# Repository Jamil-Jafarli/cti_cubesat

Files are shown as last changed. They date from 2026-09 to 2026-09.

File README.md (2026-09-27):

# Honeypot CubeSat CTI

A bench prototype of a **space cyber-threat-intelligence (CTI) platform built
on honeypot CubeSats**: a decoy satellite listens to its uplink, measures and
scores every frame it receives, fingerprints the transmitter, and sends its
records to a ground station that turns them into alerts, attacker profiles
and shareable indicators. The same board, switched to member mode, becomes
the accept/block gate a protected satellite would run.

The bench runs the whole chain over a real radio link with three low-cost
nodes: a Raspberry Pi Pico that plays ground stations and attackers, an ESP32
honeypot node, and a Raspberry Pi 4 ground station with a web portal.

| Uplink transmitter | Honeypot node | CTI ground station |
|---|---|---|
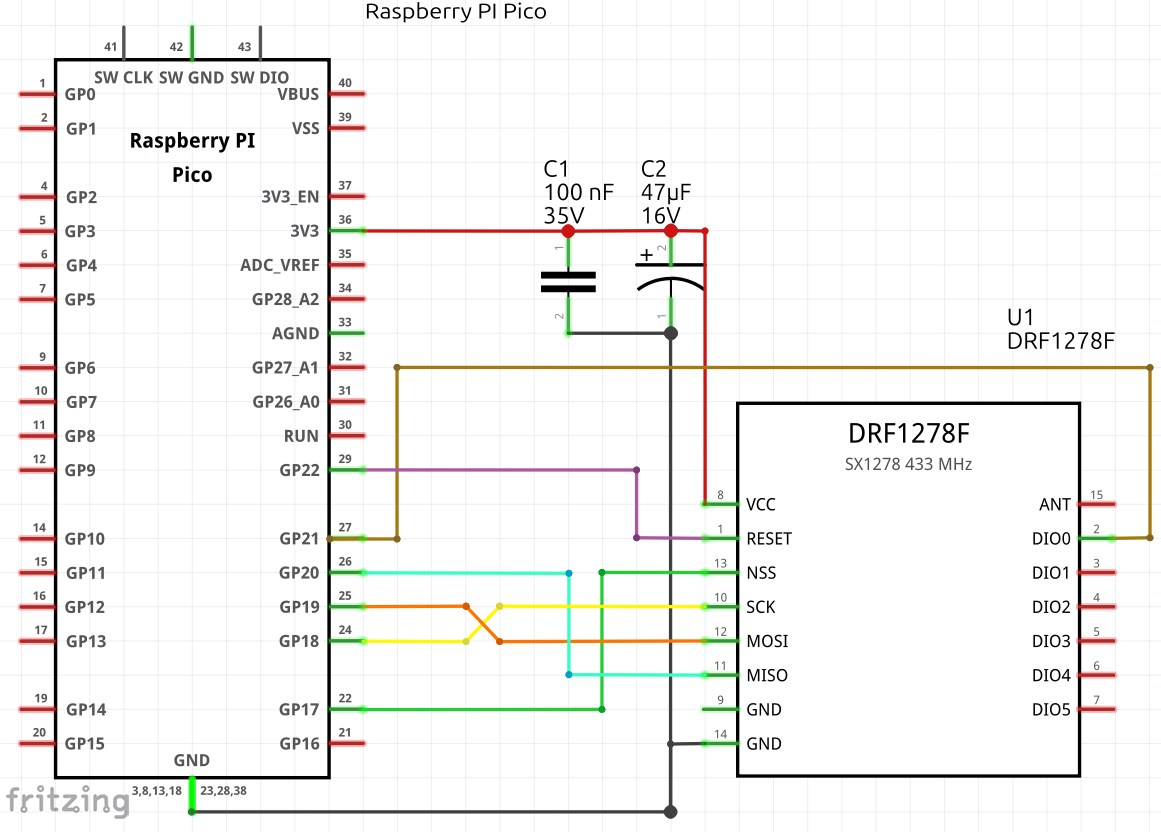
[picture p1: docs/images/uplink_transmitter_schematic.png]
Uplink transmitter schematic
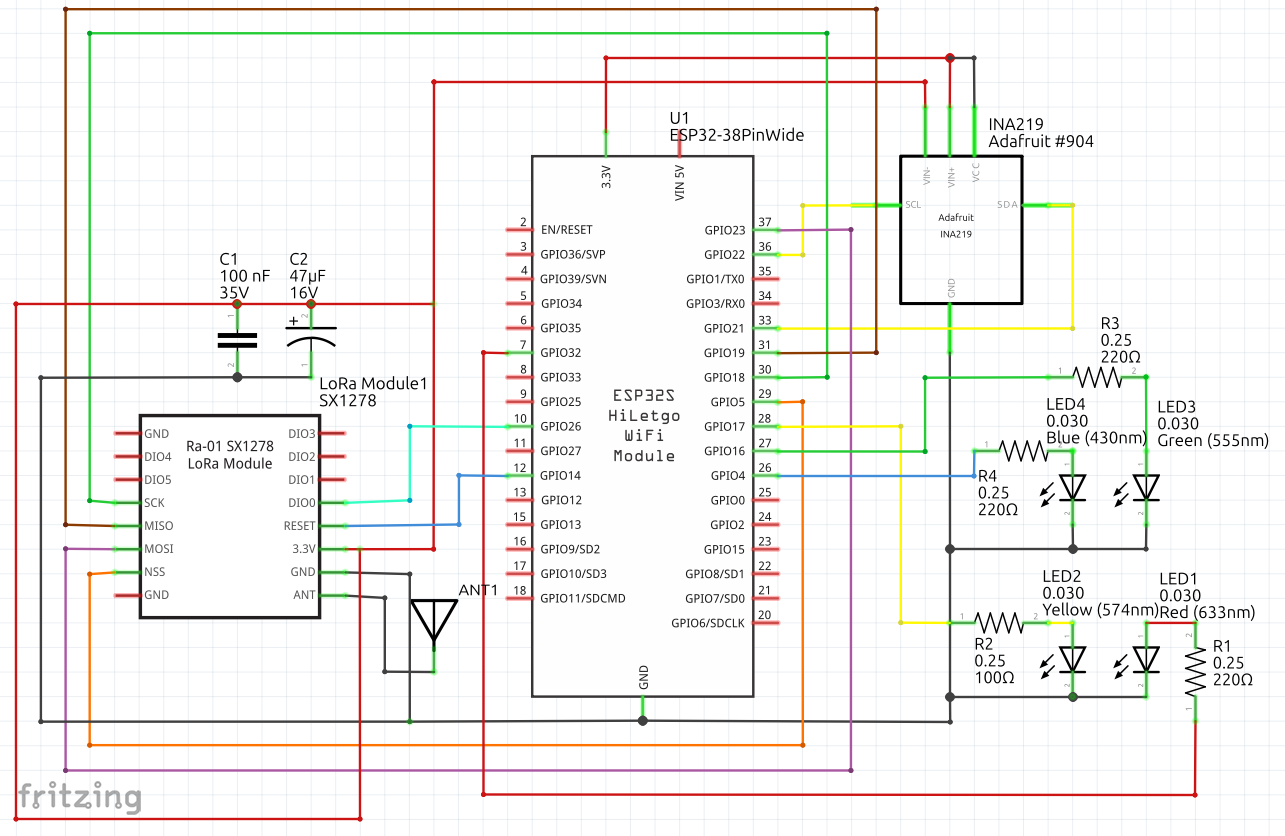
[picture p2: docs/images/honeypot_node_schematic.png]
Honeypot node schematic
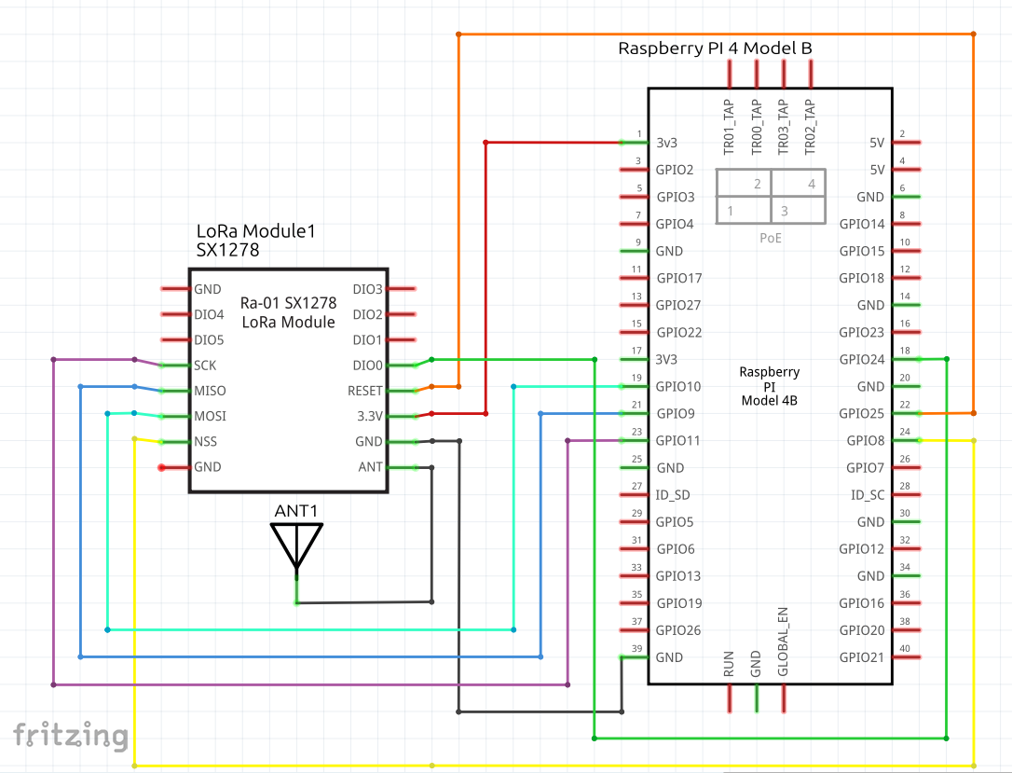
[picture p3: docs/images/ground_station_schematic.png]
Ground station schematic
|  |  |  |
| Raspberry Pi Pico + DRF1278F | ESP32 + Ra-01 + INA219 | Raspberry Pi 4 + Ra-01 |

## Contents

- [How it works](#how-it-works)
- [Results](#results)
- [Repository layout](#repository-layout)
- [Quick start without hardware](#quick-start-without-hardware)
- [Building the bench](#building-the-bench)
- [Running a session](#running-a-session)
- [Detection in brief](#detection-in-brief)
- [Reproducing the results](#reproducing-the-results)
- [Limitations](#limitations)
- [Documentation](#documentation)
- [Safety and regulations](#safety-and-regulations)
- [Background](#background)
- [License](#license)

## How it works

The concept has three parts:

- **Honeypot satellites** look like ordinary CubeSats, accept a small set of
  harmless commands, and record the RF metadata of every uplink frame,
  valid or not. They are the sensors of the network.
- The **ground platform** receives their records, analyses them, and builds
  the CTI database: alerts, attacker profiles, transmitter signatures.
- **Member satellites** run the same board as a gate: before a command is
  executed, the board checks it against the ground-built blocklist and its
  own allowlist, and answers accept or block.

The bench maps these onto three nodes:

```
  Uplink transmitter             Honeypot node                     CTI ground station
  Raspberry Pi Pico + DRF1278F   ESP32 + Ra-01 + INA219            Raspberry Pi 4 + Ra-01
 ┌─────────────────────────┐    ┌────────────────────────────┐    ┌────────────────────────────┐
 │ five ground stations    │    │ carrier offset (AFC), RSSI │    │ cti_receiver               │
 │ and five attack types   │    │ 7-indicator anomaly score  │    │ hny_server.py:             │
 │ AX.25 UI frames, 2-FSK  │───▶│ fuzzy transmitter match    │───▶│  SQLite, pass fit,         │
 │ 433.5 MHz, 2 dBm        │ RF │ fingerprint whitelist      │ RF │  9 detection rules,        │
 │ simulated pass Doppler  │    │ record stored in flash     │    │  profiles, STIX/MISP/CSV   │
 └─────────────────────────┘    │ member mode: accept/block  │    │ web portal on port 8700    │
          uplink                └────────────────────────────┘    └────────────────────────────┘
                                   downlink of stored records
```

All three radios are SX1278 transceivers driven by the same library
(RadioLib 7.7.1) and the same framing and detection code
(`libraries/HnyProto`), so the ground station also serves as a reference
receiver for the uplink.

A flight version, a 1U CubeSat plug-in board with the same ESP32 and a single
SX1278 receiver on one antenna, has been designed but not built. Everything
in this repository, and every number below, is from the bench.

## Results

From the bench campaign of 25 September 2026 (raw data in
[`data/`](data/2026-09-25-campaign), analysis in
[docs/reproducing.md](docs/reproducing.md)):

| Measurement | Result |
|---|---|
| Uplink capture, 15-minute scenario | 128 of 147 frames (87 %); 119 of 120 before the bench was physically disturbed |
| Carrier-offset accuracy, Doppler-free frames | −0.06 ± 0.20 kHz; 53 of 53 within ±0.4 kHz |
| Onboard processing per frame (ESP32, 240 MHz) | 290 µs mean, 347 µs max (x86_64 desktop: 195 µs) |
| Downlink of the stored records | 148 of 148, in each of two passes |
| Ground analysis | every attack record raised at least one alert, impersonations critical ones; no legitimate record flagged |
| Member mode | 11 of 11 frames from blocklisted sources blocked; 22 of 23 legitimate frames accepted |
| Honeypot throughput | 97 % capture at 0.9 s frame spacing, 9 % at 0.5 s |
| Radio power (Ra-01 supply) | 52 mW receiving, 228 mW transmitting at 2 dBm |
| Synthetic dataset (150 packets) | 32 of 32 injected attacks detected, no false positives |

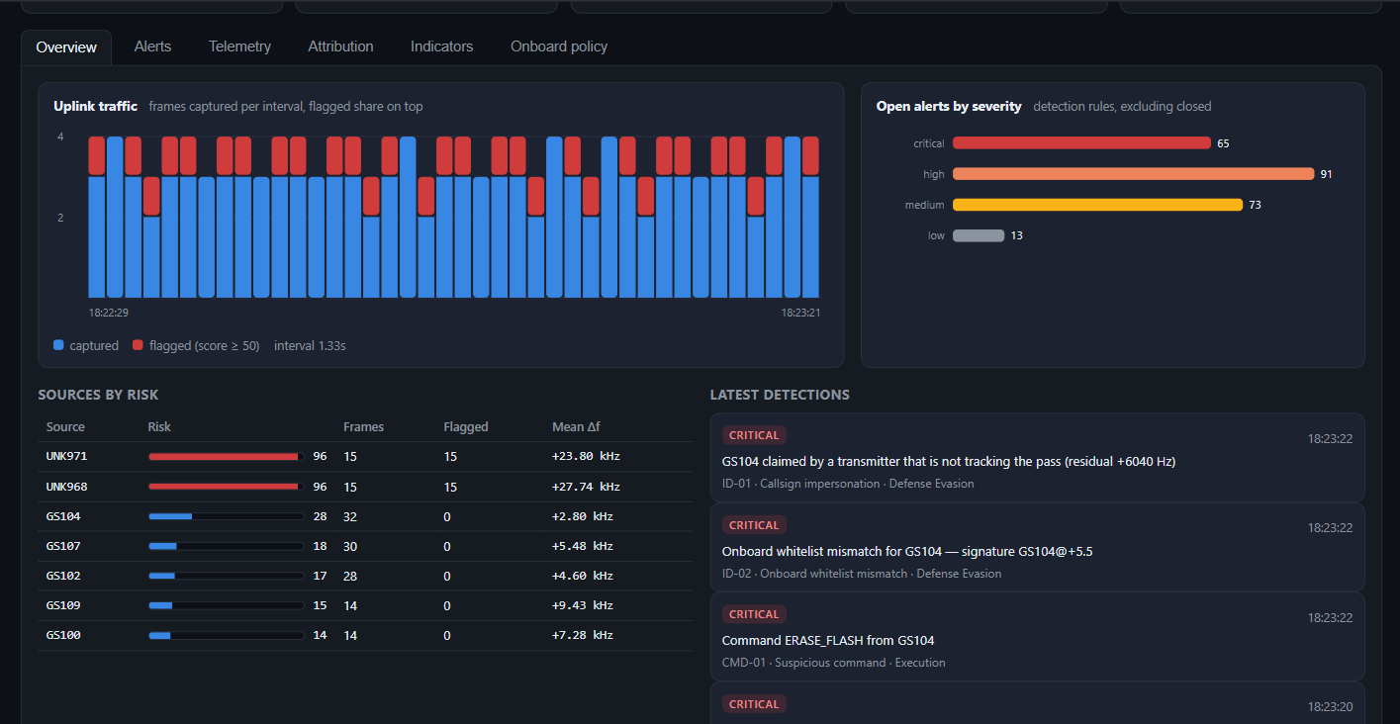
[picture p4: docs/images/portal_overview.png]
Portal overview


## Repository layout

```
firmware/
  honeypot_node/          ESP32: capture, score, fingerprint, store, downlink; member mode
  uplink_transmitter/     Pico: five ground stations and five attack types
  link_test/              Pico: numbered frames for link measurement and calibration
libraries/HnyProto/       shared header-only library: AX.25, registry, detection, record formats
ground_station/
  receiver/               cti_receiver: Raspberry Pi downlink receiver (C++, RadioLib + lgpio)
  server/                 hny_server.py, cti_engine.py, web portal, systemd unit
simulation/               synthetic-data pipeline: generator, detector, figures, dashboard
analysis/                 bench logger and the scripts behind the published figures
data/2026-09-25-campaign/ raw logs and ground database of the bench campaign
tools/uplink_monitor/     live view of the transmitted uplink (runs next to the Pico)
hardware/                 Fritzing sketches of the three nodes and a DRF1278F part
docs/                     hardware, firmware, ground station, protocol, detection, reproduction
```

## Quick start without hardware

The ground server and portal run on any computer with Python 3.10 or newer,
driven by the synthetic dataset:

```sh
git clone https://github.com/Jamil-Jafarli/cti_cubesat.git
cd cti_cubesat
pip install -r simulation/requirements.txt
cd ground_station/server
python3 hny_server.py --simulate --reset
# open http://127.0.0.1:8700
```

To re-run the detection pipeline on the synthetic data and produce its
figures, run `python3 export.py` in `simulation/`. For the Streamlit
dashboard, run `streamlit run dashboard.py` there.

## Building the bench

### Parts

| Node | Parts |
|---|---|
| Uplink transmitter | Raspberry Pi Pico, Dorji DRF1278F (SX1278, 433 MHz) |
| Honeypot node | ESP32-WROOM-32D DevKit, Ai-Thinker Ra-01 (SX1278, 433 MHz), INA219 breakout (0.1 Ω shunt), red / amber / green / blue LEDs with 300 / 200 / 300 / 200 Ω resistors |
| CTI ground station | Raspberry Pi 4 Model B, Ai-Thinker Ra-01 |
| Each radio | 100 nF ceramic + 10–47 µF electrolytic across 3.3 V and GND at the module; 17.3 cm wire antenna |

The radio modules are 3.3 V only and have 1.27 mm pads; solder thin wires to
them. The full bill of materials and notes on power, decoupling and antennas
are in [docs/hardware.md](docs/hardware.md).

### Wiring

**Uplink transmitter** (DRF1278F → Pico)

| DRF1278F | SCK | MOSI | MISO | NSS | RESET | DIO0 | VCC | GND |
|---|---|---|---|---|---|---|---|---|
| Pico | GP18 | GP19 | GP20 | GP17 | GP22 | GP21 | 3V3(OUT) | GND |

Uplink transmitter schematic

**Honeypot node** (Ra-01, INA219, LEDs → ESP32)

| Ra-01 | SCK | MISO | MOSI | NSS | RESET | DIO0 | 3.3V | GND |
|---|---|---|---|---|---|---|---|---|
| ESP32 | IO18 | IO19 | IO23 | IO5 | IO14 | IO26 | via INA219 (below) | GND |

| INA219 | VIN+ | VIN− | VCC | GND | SDA | SCL |
|---|---|---|---|---|---|---|
| connects to | ESP32 3V3 | Ra-01 3.3V | ESP32 3V3 | GND | IO21 | IO22 |

| LED (anode via resistor, cathode to GND) | red | amber | green | blue |
|---|---|---|---|---|
| ESP32 | IO32 | IO17 | IO16 | IO4 |

Honeypot node schematic

**CTI ground station** (Ra-01 → Raspberry Pi 4; header pin in brackets)

| Ra-01 | SCK | MISO | MOSI | NSS | RESET | DIO0 | 3.3V | GND |
|---|---|---|---|---|---|---|---|---|
| Pi 4 | GPIO11 (23) | GPIO9 (21) | GPIO10 (19) | GPIO8 / CE0 (24) | GPIO25 (22) | GPIO24 (18) | 3V3 (17) | GND (20) |

Ground station schematic

The ground-station schematic takes 3V3 and GND from header pins 1 and 39;
any 3V3 and GND pin works. The Fritzing sources of all three schematics are
in [`hardware/`](hardware).

### Firmware

Tested with the esp32 core 2.0.17, the arduino-pico (rp2040) core 6.1.0 and
RadioLib 7.7.1:

```sh
arduino-cli config add board_manager.additional_urls \
  https://github.com/earlephilhower/arduino-pico/releases/download/global/package_rp2040_index.json
arduino-cli core update-index
arduino-cli core install esp32:esp32@2.0.17 rp2040:rp2040@6.1.0
arduino-cli lib install RadioLib@7.7.1

arduino-cli compile -b esp32:esp32:esp32 --library libraries/HnyProto firmware/honeypot_node
arduino-cli upload  -b esp32:esp32:esp32 -p /dev/ttyUSB0 firmware/honeypot_node

arduino-cli compile -b rp2040:rp2040:rpipico --library libraries/HnyProto firmware/uplink_transmitter
arduino-cli upload  -b rp2040:rp2040:rpipico -p /dev/ttyACM0 firmware/uplink_transmitter
```

With the Arduino IDE, copy `libraries/HnyProto` into your sketchbook's
`libraries` folder and install RadioLib 7.7.1 from the Library Manager.
See [docs/firmware.md](docs/firmware.md) for configuration, serial output and
calibration.

### Ground station

On the Raspberry Pi (Raspberry Pi OS):

```sh
sudo apt install git cmake g++ liblgpio-dev python3
sudo raspi-config nonint do_spi 0
git clone https://github.com/Jamil-Jafarli/cti_cubesat.git ~/cti_cubesat
~/cti_cubesat/ground_station/receiver/build.sh
cd ~/cti_cubesat/ground_station/server
python3 hny_server.py --radio --host 0.0.0.0
# portal: http://<pi-address>:8700
```

To start it at boot, adjust and install `ground_station/server/cti-server.service`
(see [docs/ground-station.md](docs/ground-station.md)).

### Calibration

The two radios' crystals differ by a few kHz, and the difference changes when
a module is replaced or resoldered. Measure it once on your bench with
`firmware/link_test` and `analysis/linktest_analysis.py`, and set `CALIB_HZ`
in `firmware/honeypot_node/honeypot_node.ino`
([procedure](docs/firmware.md#calibration)). A calibrated node reads
Doppler-free frames to within ±0.4 kHz.

## Running a session

1. Power the three nodes 1–2 m apart, each with its antenna.
2. Open the honeypot's serial monitor (115200 baud). At boot it reports the
   INA219, the noise floor and its RSSI trigger level.
3. Let the uplink transmitter run. Every frame the honeypot receives prints an
   `[rx]` line with the measured offset, score, class and whitelist state, and
   the LEDs show the last verdict. `tools/uplink_monitor` shows the
   transmitted side live.
4. Stop the transmitter and send `D` to the honeypot (or press BOOT). Its
   stored records are downlinked, analysed on the ground and shown in the
   portal.

Honeypot serial commands:

| Key | Action |
|---|---|
| `D` | downlink every stored record |
| `S` | status JSON: store, receiver counters, processing time, heap, stack |
| `E` | erase the record store |
| `R` | reset the timing counters |
| `M` | toggle honeypot / member mode |
| `F` / `A` / `X` | show the whitelist / enrol the last transmitter / clear the whitelist |
| `P` | radio power profile (receive, standby, sleep, 2 dBm carrier) via the INA219 |
| `Q` | RSSI scan of 433.40–433.60 MHz (all transmitters off) |

## Detection in brief

Every frame gets an anomaly score of 0–100 from seven weighted indicators;
50 or more flags it:

| Indicator | Fires when | Weight |
|---|---|---:|
| Frequency deviation | carrier more than 20 kHz off the centre | 25 |
| Doppler mismatch | Doppler residual larger than 700 Hz | 25 |
| Unexpected modulation | modulation differs from the expected profile | 15 |
| Suspicious command | e.g. `REBOOT`, `ERASE_FLASH`, an unknown opcode | 15 |
| Malformed packet | AX.25 FCS does not verify | 10 |
| Unknown source | callsign not in the registry | 5 |
| Probing | less than 2 s since the previous frame | 5 |

Independently, a fuzzy match against the ground-station registry classifies
the transmitter as known, suspicious or attacker:

```
S = 0.45 · (1 − |Δfreq| / 25 kHz) + 0.25 · (1 − |Δdrift| / 1 ppm) + 0.30 · [modulation matches]
```

A callsign is only text, so the honeypot binds each whitelisted callsign to
the carrier offset its real transmitter uses (the **transmitter signature**,
e.g. `GS104@+0.0`). A frame that carries an enrolled callsign from a
different radio is reported as a whitelist mismatch, and in member mode it
loses the allowlist override.

On the ground, the server fits the pass to all records, recomputes every
score, and runs nine rules (off-frequency carrier, Doppler residual, callsign
impersonation, whitelist mismatch, suspicious command, unregistered source,
probing burst, malformed frame, sustained campaign). It groups records into
source profiles with a risk score and offers callsigns, signatures and
commands as indicators with confidence and TLP marking, exportable as
STIX 2.1, MISP or CSV. Details: [docs/detection.md](docs/detection.md).

## Reproducing the results

```sh
cd analysis
python3 scenario_analysis.py ../data/2026-09-25-campaign/scenario_run.json ../data/2026-09-25-campaign/ground.db
python3 member_analysis.py   ../data/2026-09-25-campaign/member_run.json
python3 linktest_analysis.py ../data/2026-09-25-campaign/linktest_900ms.json
```

These reproduce the numbers in [Results](#results) from the raw campaign
data. [docs/reproducing.md](docs/reproducing.md) shows the expected output and
how to run the same measurements on your own bench.

## Limitations

- **Synthetic and scripted evaluation.** The detection rates come from a
  synthetic dataset whose anomalies follow the same features the detector
  scores, and the bench scenarios were written by us. Neither reflects an
  adaptive, real attacker.
- **Prototype figures.** All measurements are from a classic ESP32 and one
  SX1278 per node. The power of the whole node was not measured (only the
  radio's), and capture depended on the physical state of the bench.
- **Throughput.** The honeypot scores, fingerprints and writes each frame to
  flash before it listens again, so it loses most frames sent faster than
  about one per second. A transmitter can use this to blind it. Buffering
  records in RAM and writing them off the receive path is the obvious fix and
  is not implemented.
- **Modulation.** An SX127x packet receiver decodes only its own modulation,
  so the unexpected-modulation indicator never fires on the bench. It needs a
  receiver with IQ output or an SDR.
- **Fingerprint resolution.** The bench measures the carrier offset to about
  0.4 kHz and cannot measure oscillator drift, while the registry assumes
  sub-kHz signatures. The 1:N fuzzy match only works on a small,
  mission-specific registry; a decision about a claimed identity should rest
  on the 1:1 whitelist check.
- **Onboard Doppler estimate.** Without an orbit model the honeypot estimates
  the pass Doppler from the cooperating stations. The estimate lags the
  fastest part of the pass, needs about 20 s after a restart, and assumes the
  cooperating stations are the majority of the traffic.
- **Whitelist enrolment** is trust on first use.
- **Not implemented:** distribution of the CTI blocklist to member
  satellites, transmitter geolocation from the Doppler curve, a TAXII server,
  authentication of the portal and API.

## Documentation

| Document | Content |
|---|---|
| [docs/hardware.md](docs/hardware.md) | bill of materials, wiring, schematics, power, antennas, Fritzing files |
| [docs/firmware.md](docs/firmware.md) | toolchain, build and upload, configuration, serial commands and output, calibration |
| [docs/ground-station.md](docs/ground-station.md) | Raspberry Pi setup, server options, systemd, portal, HTTP API, troubleshooting |
| [docs/protocol.md](docs/protocol.md) | radio channel, AX.25 frames, record and downlink formats |
| [docs/detection.md](docs/detection.md) | indicators, fuzzy match, signatures and whitelist, member mode, ground rules, profiles, indicators |
| [docs/reproducing.md](docs/reproducing.md) | reproducing every published figure from the raw data, and on your own bench |

## Safety and regulations

The bench transmits at 2 dBm on 433.5 MHz, inside the 433.05–434.79 MHz ISM
band, over a distance of 1–2 m. Check the rules for short-range devices in
your country before transmitting, and always connect an antenna before a
radio transmits. The flight concept uses the amateur-satellite band, which
requires a licence. This project is for research and education: do not
transmit to satellites you do not operate.

## Background

The bench was built for the paper *Space Cyber Threat Intelligence Platform
Using Honeypot CubeSats for Attacker Identification*, prepared for the
International Astronautical Congress (IAC 2026).

The project builds on RadioLib, lgpio, Streamlit, pandas and matplotlib, and
on community Fritzing parts for the Ra-01, ESP32 DevKit, INA219 and
Raspberry Pi Pico.

## License

MIT, see [LICENSE](LICENSE). Third-party components (RadioLib, lgpio, the
Python packages and the community Fritzing parts) keep their own licences.

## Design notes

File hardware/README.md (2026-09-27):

# Hardware files

| File | Content |
|---|---|
| `fritzing/uplink_transmitter.fzz` | Raspberry Pi Pico + DRF1278F |
| `fritzing/honeypot_node.fzz` | ESP32 DevKit + Ra-01 + INA219 + four LEDs |
| `fritzing/ground_station.fzz` | Raspberry Pi 4 + SX1278 radio (drawn with the DRF1278F symbol; the bench uses a Ra-01 with the same connections) |
| `fritzing/parts/DRF1278F_Dorji_SX1278.fzpz` | Fritzing part for the Dorji DRF1278F (17 × 17 mm, 15 castellated pads at 1.27 mm), made from the DRF1278F datasheet Rev 1.1 |

Open the part file in Fritzing first (File → Open), so that the sketches that
use it find it. The other parts are embedded in the sketches.

Wiring tables, the bill of materials and notes on power and antennas are in
[docs/hardware.md](../docs/hardware.md).

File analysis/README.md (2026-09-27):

# Analysis

| Script | Purpose |
|---|---|
| `benchlog.py` | logs the transmitter Pico and the honeypot side by side with host timestamps (needs pyserial) |
| `benchparse.py` | shared parsing and frame matching |
| `linktest_analysis.py` | link test: capture and carrier-offset error per offset; calibration |
| `scenario_analysis.py` | scenario run: capture, onboard and ground verdicts, carrier-offset error, alerts per scenario |
| `member_analysis.py` | member-mode run: verdicts per scenario |

```sh
python3 scenario_analysis.py ../data/2026-09-25-campaign/scenario_run.json ../data/2026-09-25-campaign/ground.db
```

The full procedure and the expected output are in
[docs/reproducing.md](../docs/reproducing.md).

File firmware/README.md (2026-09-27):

# Firmware

| Sketch | Board | Role |
|---|---|---|
| [`honeypot_node`](honeypot_node/honeypot_node.ino) | ESP32 Dev Module | the honeypot's detection board: capture, score, fingerprint, store, downlink; member mode |
| [`uplink_transmitter`](uplink_transmitter/uplink_transmitter.ino) | Raspberry Pi Pico | uplink scenario: five ground stations and five attack types |
| [`link_test`](link_test/link_test.ino) | Raspberry Pi Pico | link measurement and calibration |

All sketches need RadioLib 7.7.1 and the shared library in
[`../libraries/HnyProto`](../libraries/HnyProto):

```sh
arduino-cli compile -b esp32:esp32:esp32     --library libraries/HnyProto firmware/honeypot_node
arduino-cli compile -b rp2040:rp2040:rpipico --library libraries/HnyProto firmware/uplink_transmitter
arduino-cli compile -b rp2040:rp2040:rpipico --library libraries/HnyProto firmware/link_test
```

Each sketch starts with a header that lists its wiring, build settings and
serial commands. Toolchain, configuration, serial output and calibration are
described in [docs/firmware.md](../docs/firmware.md).

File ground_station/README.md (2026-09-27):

# Ground station

Runs on a Raspberry Pi 4 with a Ra-01 on SPI0.

| Folder | Content |
|---|---|
| [`receiver`](receiver) | `cti_receiver` (C++, RadioLib + lgpio): receives the honeypot's downlink and prints one `CTI,<csv>` line per record |
| [`server`](server) | `hny_server.py`: stores the records (SQLite), runs the ground analysis and serves the portal on port 8700; `cti_engine.py`: detection rules, profiles, indicators and STIX/MISP/CSV export; `web/`: the portal; `cti-server.service`: systemd unit |

```sh
sudo apt install cmake g++ liblgpio-dev python3
sudo raspi-config nonint do_spi 0
receiver/build.sh
cd server && python3 hny_server.py --radio --host 0.0.0.0
```

Without hardware: `python3 hny_server.py --simulate --reset` (needs
`simulation/requirements.txt`). Setup, options, the portal, the HTTP API and
troubleshooting are described in [docs/ground-station.md](../docs/ground-station.md).

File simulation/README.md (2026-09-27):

# Simulation

The synthetic-data version of the detection pipeline: it generates labelled
uplink telemetry for three simulated honeypot satellites, scores it with the
same indicators and fuzzy match as the firmware, and produces CTI records,
figures and a dashboard.

| File | Content |
|---|---|
| `profiles.py` | node frequencies, ground-station registry, indicator weights and thresholds |
| `generator.py` | synthetic telemetry: legitimate passes with Doppler and drift, and injected attacks |
| `detector.py` | anomaly score, fuzzy transmitter match, CTI records, evaluation |
| `database.py` | SQLite storage of CTI records |
| `export.py` | the whole pipeline: data, records, figures and the evaluation printout |
| `profile_resources.py` | processing time, memory and throughput of the pipeline |
| `dashboard.py` | Streamlit dashboard |

```sh
pip install -r requirements.txt
python3 export.py                  # writes data/ and out/, prints the evaluation
python3 profile_resources.py       # timing on this machine
streamlit run dashboard.py         # interactive dashboard
```

The ground server's `--simulate` mode imports `generator.py` and `detector.py`
from here to fill the portal without hardware.

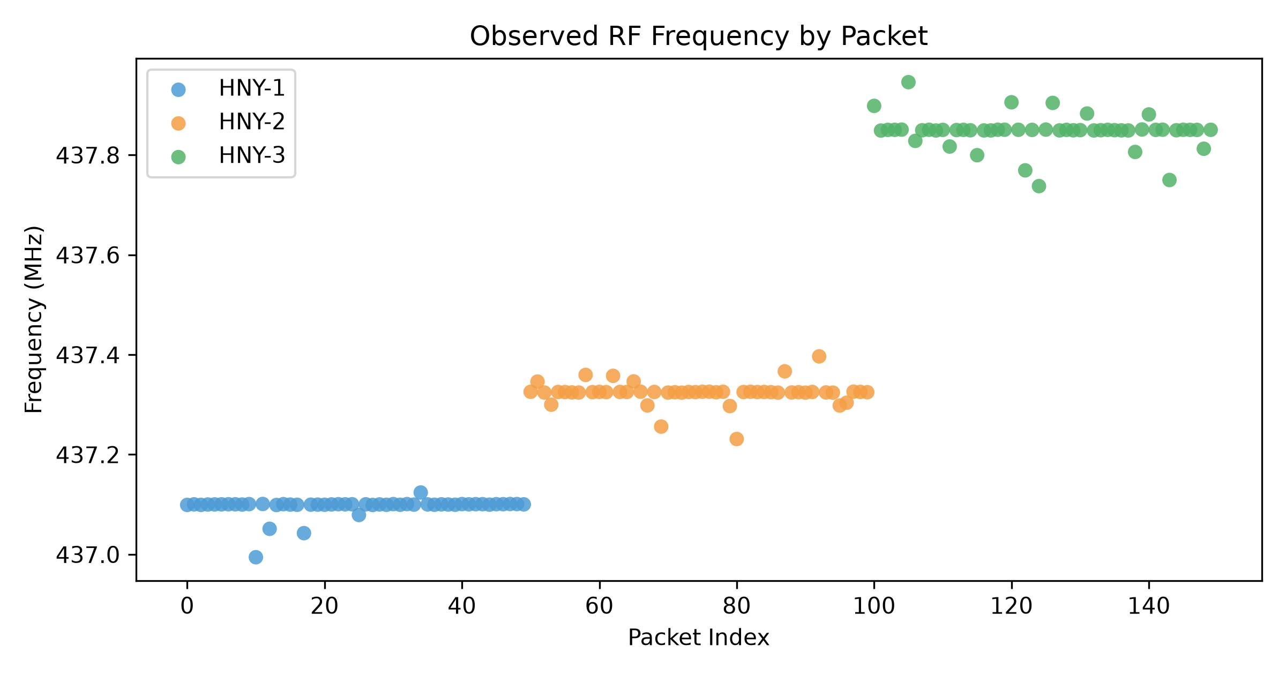
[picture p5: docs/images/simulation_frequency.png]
Carrier frequency per packet


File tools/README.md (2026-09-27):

# Tools

## Uplink monitor

`uplink_monitor/uplink_monitor.py` shows the frames the uplink transmitter
sends, live, in a browser. Run it on the computer the Pico is connected to:

```sh
python3 tools/uplink_monitor/uplink_monitor.py --serial /dev/ttyACM0
python3 tools/uplink_monitor/uplink_monitor.py --demo      # no hardware
# open http://127.0.0.1:8701
```

It reads the `[up] ...` lines of `firmware/uplink_transmitter`, keeps the last
400 frames in memory and stores nothing on disk. Only the standard library is
needed, plus pyserial for `--serial`. The serial port can be read by only one
program at a time, so stop `analysis/benchlog.py` while the monitor runs.

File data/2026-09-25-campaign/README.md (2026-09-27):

# Bench campaign, 25 September 2026

Raw data of the measurement campaign reported in the documentation
([docs/reproducing.md](../../docs/reproducing.md)). Radio supply of the
honeypot: ESP32 3V3 → INA219 → Ra-01. Honeypot store and ground database
were empty at the start.

| File | Content |
|---|---|
| `scenario_run.json` | 15-minute run of `firmware/uplink_transmitter`: transmitter log (`pico`) and honeypot log (`esp`), host timestamps |
| `ground.db` | ground-station database after the downlink (148 of 148 records): tables `packets`, `alerts`, `indicator_state` |
| `honeypot_status.json` | the honeypot's status report (`S`) after the uplink: processing time, heap, stack, receiver counters |
| `power.json` | three runs of the honeypot's radio power profile (`P`) |
| `linktest_900ms.json` | `firmware/link_test` at 0.9 s frame spacing, transmitter and honeypot logs |
| `linktest_500ms.json` | the same at 0.5 s frame spacing |
| `member_run.json` | 6-minute run with the honeypot in member mode, after the bench had been disturbed |

The honeypot's serial log becomes unreliable after about 800 s of the scenario
run (USB passthrough), so capture is computed from the ground database, which
holds the honeypot's complete store.

```sh
cd analysis
python3 scenario_analysis.py ../data/2026-09-25-campaign/scenario_run.json ../data/2026-09-25-campaign/ground.db
```

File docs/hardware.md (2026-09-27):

# Hardware

The bench has three nodes. All three radios are SX1278 transceivers on the
433 MHz ISM band, driven by the same library (RadioLib 7.7.1) and the same
framing code (`libraries/HnyProto`).

| Node | Role | Board | Radio |
|---|---|---|---|
| Uplink transmitter | plays five ground stations and an attacker | Raspberry Pi Pico | Dorji DRF1278F |
| Honeypot node | the CubeSat's detection board | ESP32-WROOM-32D development board | Ai-Thinker Ra-01 |
| CTI ground station | receives the downlink, runs the server and portal | Raspberry Pi 4 Model B | Ai-Thinker Ra-01 |

## Bill of materials

| Qty | Part | Notes |
|---|---|---|
| 1 | Raspberry Pi Pico | uplink transmitter (the same board runs the link test) |
| 1 | Dorji DRF1278F module (SX1278, 433 MHz) | castellated, 1.27 mm pitch |
| 1 | ESP32-WROOM-32D development board | 30- or 38-pin DevKit, "ESP32 Dev Module" in the Arduino IDE |
| 2 | Ai-Thinker Ra-01 module (SX1278, 433 MHz) | honeypot node and ground station, 1.27 mm pitch |
| 1 | INA219 current-monitor breakout, 0.1 Ω shunt | radio supply monitor on the honeypot node |
| 1 | Raspberry Pi 4 Model B, Raspberry Pi OS | ground station |
| 4 | 3 mm or 5 mm LEDs: red, amber, green, blue | verdict indicators |
| 4 | resistors: 220 Ω (red, green, blue), 100 Ω (amber) | LED series resistors |
| 3 | 100 nF ceramic capacitor | one per radio module |
| 3 | 10–47 µF electrolytic capacitor, ≥ 6.3 V | one per radio module |
| 3 | 17.3 cm straight wire (or a 433 MHz spring antenna) | quarter-wave antenna for each radio |
| – | perfboard, thin wire, headers, USB cables | |

The SX1278 modules are 3.3 V parts: never connect them to 5 V. Both module
types have 1.27 mm pads and do not fit a breadboard; solder thin wires to them
or use a breakout adapter.

## Wiring

Pins are given by name. On the Raspberry Pi 4 the physical header position is
added, because the header itself is not labelled.

### Uplink transmitter: DRF1278F → Raspberry Pi Pico

| DRF1278F | Pico |
|---|---|
| SCK | GP18 |
| MOSI | GP19 |
| MISO | GP20 |
| NSS | GP17 |
| RESET | GP22 |
| DIO0 | GP21 |
| VCC | 3V3(OUT) |
| GND (both) | GND |
| ANT | 17.3 cm wire |

MISO must be an SPI0 RX-capable pin (GP0, GP4, GP16 or GP20); change `PIN_MISO`
in the sketch if you use another one. DIO1–DIO5 stay unconnected.

Uplink transmitter schematic

### Honeypot node: Ra-01, INA219 and LEDs → ESP32

| From | To (ESP32) |
|---|---|
| Ra-01 SCK | IO18 |
| Ra-01 MISO | IO19 |
| Ra-01 MOSI | IO23 |
| Ra-01 NSS | IO5 |
| Ra-01 RESET | IO14 |
| Ra-01 DIO0 | IO26 |
| Ra-01 3.3V | INA219 VIN− |
| INA219 VIN+ | 3V3 (a separate wire) |
| INA219 VCC | 3V3 |
| INA219 GND | GND |
| INA219 SDA | IO21 |
| INA219 SCL | IO22 |
| Ra-01 GND (all three) | GND |
| red LED anode, through 220 Ω | IO32 |
| amber LED anode, through 100 Ω | IO17 |
| green LED anode, through 220 Ω | IO16 |
| blue LED anode, through 220 Ω | IO4 |
| LED cathodes | GND |

The radio's supply runs ESP32 3V3 → INA219 VIN+ → shunt → VIN− → Ra-01 3.3V,
so the INA219 measures the radio's current and nothing else. The node works
without the INA219 if VIN+ and VIN− are bridged; only the `P` power profile is
then unavailable.

Keep IO0 (BOOT button), IO2, IO12, IO15 and IO6–IO11 free. IO16 and IO17 are
free on WROOM modules only; on a WROVER board move the green and amber LEDs
to other pins. IO25 is an optional COM_TX_ACTIVE input (active low, internal
pull-up) that parks the receiver while the satellite's own radio transmits;
leave it unconnected on the bench.

LED meanings:

| LED | Honeypot mode | Member mode |
|---|---|---|
| red | flagged or classified as attacker | blocked |
| amber | suspicious | allowlist override or spoof suspect |
| green | known ground station | accepted |
| blue | downlink in progress | downlink in progress |

The red, amber and green LEDs hold the last verdict until the next frame.

Honeypot node schematic

### CTI ground station: Ra-01 → Raspberry Pi 4

| Ra-01 | Raspberry Pi 4 | Header pin |
|---|---|---|
| 3.3V | 3V3 | 17 |
| GND | GND | 20 |
| SCK | GPIO11 (SPI0 SCLK) | 23 |
| MISO | GPIO9 (SPI0 MISO) | 21 |
| MOSI | GPIO10 (SPI0 MOSI) | 19 |
| NSS | GPIO8 (SPI0 CE0) | 24 |
| RESET | GPIO25 | 22 |
| DIO0 | GPIO24 | 18 |
| ANT | 17.3 cm wire | – |

Header pin 1 is the corner farthest from the USB and Ethernet ports (square
solder pad); odd pins are on the inner row. Pins 2 and 4 carry 5 V; do not
connect the radio there. The kernel's SPI driver drives NSS (CE0), so SPI must
be enabled (`sudo raspi-config nonint do_spi 0`).

The schematic below takes 3V3 and GND from header pins 1 and 39; any 3V3 and
GND pin works.

Ground station schematic

## Power and decoupling

Put a 100 nF ceramic and a 10–47 µF electrolytic capacitor across each radio
module's 3.3 V and GND, as close to the module as possible (positive lead of
the electrolytic to 3.3 V). On the bench, supply dips at the radio were enough
to reset the SX1278 without resetting the microcontroller; the firmware
detects this and reconfigures the radio, but good decoupling prevents it.

Power the radios from the boards' own 3.3 V regulators. On the honeypot node
a separate switching converter in the radio supply added noise next to the
receiver and a voltage drop on mode changes, and was removed.

## Antennas and placement

Each radio needs an antenna: a 17.3 cm straight wire soldered to ANT (a
quarter wave at 433 MHz) or a 433 MHz spring antenna. Never transmit without
an antenna. Keep the Ra-01 at least 3 cm from the ESP32 board's own PCB
antenna. The bench runs at 2 dBm over 1–2 m; the received level is typically
−40 to −60 dBm.

## Fritzing files

`hardware/fritzing/` holds the Fritzing sketches of the three nodes and a
Fritzing part for the Dorji DRF1278F, which is not in the standard library.
Import `parts/DRF1278F_Dorji_SX1278.fzpz` first (File → Open), then open the
sketches. The Ra-01, ESP32 DevKit, INA219 and Raspberry Pi Pico parts are
embedded in the sketches; they come from community part libraries.

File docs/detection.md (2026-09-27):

# Detection

Detection runs in two tiers. The honeypot node scores every frame as it
arrives, fingerprints the transmitter and stores a record. The ground station
receives the stored records, analyses the whole pass again with information
the satellite does not have, raises alerts and builds the threat-intelligence
picture. The ground figures are the authoritative ones; the onboard score is
kept alongside for comparison.

The same constants are defined in `libraries/HnyProto/HnyProto.h` (firmware),
`simulation/profiles.py` (synthetic pipeline) and
`ground_station/server/cti_engine.py` (ground analysis).

## Anomaly score

Every frame gets a score of 0–100, the sum of seven weighted binary
indicators:

| Indicator | Fires when | Weight |
|---|---|---:|
| Frequency deviation | carrier more than 20 kHz from the node's centre frequency | 25 |
| Doppler mismatch | Doppler residual larger than 700 Hz | 25 |
| Unexpected modulation | modulation differs from the expected profile (GFSK in the model) | 15 |
| Suspicious command | `REBOOT`, `OVERRIDE`, `ERASE_FLASH`, `SET_MODE=DEBUG`, `DISABLE_COMMS` or an unknown opcode | 15 |
| Malformed packet | AX.25 FCS does not verify | 10 |
| Unknown source | callsign not in the ground-station registry | 5 |
| Probing | less than 2 s since the previous frame | 5 |

A frame with a score of 50 or more is **flagged**, and a CTI record is
created for it. Its confidence is `min(89.15, 42 + 0.53 × score)`; the cap is
a calibration constant, not a measured value.

On the bench the modulation indicator never fires: an SX127x packet receiver
decodes only its own modulation and sees any other one as signal strength
alone. Recognising foreign modulations needs a receiver with IQ output or an
SDR at the ground station.

The Doppler residual is the carrier offset left after the pass Doppler and
the transmitter's known offset are removed. A cooperating ground station
pre-compensates the pass Doppler, so its residual is near zero; a transmitter
without an orbit model (a typical ground attacker) stays on a fixed frequency,
and its residual follows the whole pass profile.

## Fuzzy transmitter match

Independently of the score, every frame is compared with each of the 16
ground stations in the registry. A station's signature is the residual
carrier offset of its transmitter (sub-kHz for TCXO-class references) and its
short-term oscillator drift (ppm). The similarity with one entry is

```
S = 0.45 · (1 − |Δfreq| / 25 kHz)
  + 0.25 · (1 − |Δdrift| / 1 ppm)
  + 0.30 · [modulation matches]
```

with each term clipped at zero. The best match over the registry classifies
the transmitter as **known** (S ≥ 0.85), **suspicious** (0.60 ≤ S < 0.85) or
**attacker** (S < 0.60).

The bench measures the carrier offset to about 0.4 kHz and cannot measure
oscillator drift at all (the firmware passes zero), so on the bench the
ranking rests on the frequency term. The portal shows the three weighted
terms, the runner-up and the margin for every frame, so a classification that
rests on an unmeasured term is visible as such.

The fuzzy match is a 1:N identification and only works on a small,
mission-specific registry. With thousands of stations in one database almost
any ordinary transmitter would sit within 1 kHz of some entry and be
classified as `known` under another station's name. Decisions about a claimed
identity should therefore rest on a 1:1 check of the claimed callsign's own
signature, which is what the whitelist below does.

## Transmitter signature and fingerprint whitelist

The per-record SHA-256 identifier changes with every frame, so nothing can be
whitelisted on it. What does persist from frame to frame is the physical
layer the transmitter cannot easily change: the carrier offset its oscillator
lands on. Quantised to 0.5 kHz and paired with the claimed callsign, it forms
the **transmitter signature**:

```
GS104@+0.0     the operator's own station, as enrolled
GS104@+24.5    somebody else transmitting GS104's callsign
```

The honeypot keeps a small whitelist of signatures (up to 8 entries, stored
in flash). Each entry holds a callsign, an enrolled offset and a tolerance
(1.5 kHz). A frame is checked against it on its Doppler-free residual and
gets one of three states:

| State | Meaning |
|---|---|
| none | no entry for this callsign: the whitelist has no opinion |
| match | the callsign is enrolled and the offset is within tolerance |
| mismatch | the callsign is enrolled, but the frame came from a different transmitter |

Entries are enrolled deliberately: send `A` to the honeypot right after a
known-good frame. A flight build would fill the table before launch and
update it only through an authenticated uplink. Enrolment is trust on first
use: an impersonator transmitting during enrolment would be enrolled.

### Onboard Doppler estimate

The whitelist must be checked on the residual, and the bench board has no
orbit model. Every cooperating station pre-compensates the same pass profile,
so subtracting each station's known offset from its measured offset leaves
the common Doppler motion. The median of the last eight such samples
estimates it; a fixed-frequency attacker is an outlier the median ignores.
The estimate needs three samples from known callsigns before it is used
(about 20 s on the bench scenario); until then the residual is the raw offset.

Limits of this estimate: the median lags the fastest part of the pass, so a
legitimate frame can briefly exceed the 700 Hz threshold; and it assumes the
cooperating stations are the majority of the traffic. A flight board would
take the Doppler from its orbit propagator instead.

## Member mode

On a member satellite the board is a gate, not a sensor. For every uplink
frame it gives the on-board computer a verdict and stores nothing. Two lists
decide:

- the **allowlist**: the satellite's own ground stations; it always wins, so
  an attacker cannot get a legitimate station blocked by imitating it;
- the **blocklist**: transmitter signatures from the ground platform
  (callsign plus carrier offset within a tolerance). Only entries with a
  confidence of 80 or more are acted on.

| Situation | Verdict |
|---|---|
| blocklist match, callsign not allowlisted | BLOCK |
| allowlisted callsign, whitelist match or no entry, blocklist match | ACCEPT (allowlist override) |
| allowlisted callsign, whitelist mismatch, blocklist match | BLOCK |
| allowlisted callsign, whitelist mismatch, no blocklist match | ACCEPT, marked as spoof suspect |
| no match, or an undecodable frame | ACCEPT |

The board fails open: anything it cannot positively match is accepted, so a
false positive can never make the satellite uncommandable. The bench lists
are compiled into `HnyProto.h` (`ALLOWLIST`, `BLOCKLIST`); distributing the
ground-built blocklist to member satellites over RF is not implemented.

## Ground analysis

When the downlink goes quiet the server analyses the received records:

1. **Pass fit.** The honeypot and the transmitter boot independently, so
   their clocks differ by an unknown constant. The server scans the pass
   phase in one-second steps and takes the one that minimises the median
   Doppler residual of the known stations.
2. **Rescoring.** With the fitted pass, the Doppler residual and the score of
   every record are recomputed with the weights above. These are the
   authoritative figures; the honeypot's own score is kept as
   `onboard_score`.
3. **Detection rules.** Nine rules raise alerts:

| Rule | Name | Fires when | Severity | Tactic |
|---|---|---|---|---|
| RF-01 | Off-frequency carrier | carrier more than 20 kHz off centre | high | Initial Access |
| RF-02 | Doppler residual anomaly | Doppler residual larger than 700 Hz | high | Initial Access |
| ID-01 | Callsign impersonation | a registered callsign with such a residual | critical | Defense Evasion |
| ID-02 | Onboard whitelist mismatch | the honeypot reported a whitelist mismatch | critical | Defense Evasion |
| CMD-01 | Suspicious command | suspicious command; critical if destructive (`ERASE_FLASH`, `DISABLE_COMMS`, `OVERRIDE`) | medium / critical | Execution |
| REC-01 | Unregistered source | callsign outside the registry | medium | Reconnaissance |
| REC-02 | Probing burst | less than 2 s since the previous frame | medium | Reconnaissance |
| INT-01 | Malformed frame | AX.25 FCS does not verify | low | Defense Evasion |
| AGG-01 | Sustained campaign | five or more flagged frames from one source within ten minutes | critical | Impact |

The tactic labels follow the style of ATT&CK and are used for grouping only.
Alerts are keyed by rule and frame, so re-running the analysis over the same
capture does not duplicate them. In the portal they move from open to
acknowledged to closed.

REC-02 works on the gap the receiver sees, not per source, so a burst is also
attributed to the frame that follows it.

## Profiles, indicators and sharing

Records are grouped into **source profiles** by claimed callsign. The record
identifier cannot group traffic, and true transmitter grouping would need the
drift measurement the bench lacks. Each profile has a risk score:

```
severity = 30 · flagged share
         + 25 · share of suspicious commands
         + 20 · [callsign not registered]
         + 15 · min(1, count / 20)                persistence
         + 10 · min(1, mean |carrier offset| / 20 kHz)
risk     = min(100, severity · min(1, count / 3))
```

A profile needs at least three observations to count as confirmed, and a
confirmed profile with a risk of 60 or more becomes a blocklist candidate.
One frame, however suspicious, cannot produce a high-risk profile.

Callsigns, transmitter signatures and commands are offered as **indicators**,
each with its evidence count, a TLP marking (AMBER when flagged traffic is
involved, GREEN otherwise) and a confidence:

```
confidence = min(95, 40 · min(1, count / 10) + 35 · flagged share + 25 · offset consistency)
```

The confidence is capped below 100 on purpose: a bench of two radios cannot
earn certainty. The analyst sets each indicator's disposition (watch,
blocklist, allowlist, dismissed), and the indicator set exports as a STIX 2.1
bundle, a MISP event or CSV. RF properties have no standard STIX object type,
so they are exported as custom properties rather than forced into a network
indicator. A TAXII server is not implemented.

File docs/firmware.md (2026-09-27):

# Firmware

| Sketch | Board | Purpose |
|---|---|---|
| `firmware/honeypot_node` | ESP32 Dev Module | honeypot detection board: capture, score, store, downlink; member mode |
| `firmware/uplink_transmitter` | Raspberry Pi Pico | uplink scenario: five ground stations and five attack types |
| `firmware/link_test` | Raspberry Pi Pico | link measurement: numbered frames at fixed offsets and intervals |

All three use RadioLib and the shared header-only library
`libraries/HnyProto`.

## Toolchain

Tested with:

| Component | Version |
|---|---|
| Arduino CLI / Arduino IDE 2 | any recent |
| esp32 core (Espressif) | 2.0.17 |
| rp2040 core (Earle Philhower, arduino-pico) | 6.1.0 |
| RadioLib | 7.7.1 |

The esp32 3.x core has not been tested.

## Build and upload with arduino-cli

```sh
arduino-cli config add board_manager.additional_urls \
  https://github.com/earlephilhower/arduino-pico/releases/download/global/package_rp2040_index.json
arduino-cli core update-index
arduino-cli core install esp32:esp32@2.0.17 rp2040:rp2040@6.1.0
arduino-cli lib install RadioLib@7.7.1

# honeypot node (ESP32)
arduino-cli compile -b esp32:esp32:esp32 --library libraries/HnyProto firmware/honeypot_node
arduino-cli upload  -b esp32:esp32:esp32 -p /dev/ttyUSB0 firmware/honeypot_node

# uplink transmitter (Pico); use firmware/link_test for link measurements
arduino-cli compile -b rp2040:rp2040:rpipico --library libraries/HnyProto firmware/uplink_transmitter
arduino-cli upload  -b rp2040:rp2040:rpipico -p /dev/ttyACM0 firmware/uplink_transmitter
```

If the ESP32 upload fails at the default speed (for example through a
virtual machine's USB passthrough), add `:UploadSpeed=115200` to the board
name. A Pico that does not show a serial port can be put into its bootloader
by holding BOOTSEL while plugging it in; it then mounts as a drive and takes
the `.uf2` file from the build folder.

With the Arduino IDE, copy `libraries/HnyProto` into your sketchbook's
`libraries` folder, install RadioLib 7.7.1 from the Library Manager and select
"ESP32 Dev Module" or "Raspberry Pi Pico". The honeypot needs a partition
scheme with a SPIFFS/LittleFS area (the default one has it).

## Honeypot node

### Configuration

The constants at the top of `honeypot_node.ino`:

| Constant | Default | Meaning |
|---|---|---|
| `CENTER_MHZ` | 433.5 | channel centre |
| `CALIB_HZ` | 2730 | crystal offset between this receiver and the transmitter; see calibration |
| `FLOOR_MARGIN_DB` | 15 | RSSI trigger at least this far above the noise floor |
| `FRAME_MARGIN_DB` | 30 | RSSI trigger follows the received frames at this distance below them |
| `FP_MAX` | 8 | whitelist entries |
| `FP_ENROL_TOL_KHZ` | 1.5 | whitelist tolerance on the residual |
| `DOP_WIN`, `DOP_MIN_N` | 8, 3 | Doppler estimator window and minimum samples |
| `PIN_…` | see the header | wiring |

The detection constants (weights, thresholds, registry, allowlist and
blocklist) are in `libraries/HnyProto/HnyProto.h`.

### Serial commands

Open the serial monitor at 115200 baud and send one character:

| Key | Action |
|---|---|
| `D` | downlink every stored record to the ground station (the BOOT button does the same) |
| `S` | status JSON |
| `E` | erase the record store |
| `R` | reset the timing counters |
| `M` | toggle honeypot / member mode |
| `F` | print the fingerprint whitelist |
| `A` | enrol the transmitter of the last received frame |
| `X` | clear the whitelist (fail-open until re-enrolled) |
| `P` | radio power profile: receive, standby, sleep and a 2 dBm carrier |
| `Q` | RSSI scan of 433.40–433.60 MHz in 2 kHz steps (all transmitters off) |

### Output

At boot the node reports the INA219, the measured noise floor and the RSSI
trigger level, then one line per event:

```
[rx] GS104  PING                 dev=  +5.9 res=  -0.2 dop=  -216Hz rssi=-50 score= 0 known      WL-OK
[rx] UNK971 0x7F_UNKNOWN_OPCODE  dev= +23.8 res= +17.8 dop=+17775Hz rssi=-51 score=70 attacker   FLAG
[rx] GS102  HK_DUMP              dev=  +1.9 res=  -4.0 dop=   -28Hz rssi=-50 score=10 known      BAD-FCS
[mbr] GS104  ERASE_FLASH          dev=  +0.1kHz wl=MISMATCH -> BLOCK  (blocklist)
[dl] done: 148/148 sent
```

(taken from the 2026-09-25 campaign logs in `data/`)

`dev` is the calibrated carrier offset in kHz, `res` the offset with the
onboard Doppler estimate removed, `dop` the Doppler residual. `BAD-FCS`,
`FLAG`, `WL-OK` and `WL-MISMATCH` mark the malformed-packet indicator, a
flagged frame and the whitelist state.

The status JSON (`S`):

| Field | Meaning |
|---|---|
| `stored` | records in flash |
| `fs_used`, `fs_total` | LittleFS usage, bytes |
| `wl_entries` | whitelist entries |
| `rx_raw` | every RxDone, decodable or not |
| `crc_bad` | frames dropped for a failed PHY CRC |
| `rx_stuck` | receiver restarts after a sync match that never completed |
| `radio_reinit` | times the radio was found at its reset defaults and reconfigured |
| `rx_mode_fix` | times the radio was found in standby or sleep |
| `rx_polled` | frames served from the PayloadReady flag (missed DIO0 edge) |
| `opmode`, `irq` | raw `RegOpMode` and IRQ flags |
| `rssi_floor`, `rssi_trig`, `frame_rssi` | noise floor, current trigger, average frame RSSI (dBm) |
| `blank_n`, `blank_ms` | COM_TX_ACTIVE blanking windows and total time |
| `perf_n` | frames measured since the last `R` |
| `score_avg_us`, `score_max_us` | scoring and fingerprint time per frame |
| `store_avg_us`, `store_max_us` | flash write time per frame |
| `heap_delta_min`, `heap_free`, `heap_min_free` | heap behaviour, bytes |
| `stack_hwm` | deepest stack use of the loop task, bytes |

The power profile (`P`) prints `{"evt":"power",...}` with current (mA),
voltage (V) and power (mW) of the radio for each state. The INA219 resolves
0.1 mA, so the SX1278's sleep current reads as zero.

### Calibration

The two radios' crystals differ by a few kHz, and every carrier measurement
carries that difference. It depends on the module pair and changes when a
module is replaced or resoldered, so measure it on your own bench:

1. Flash `firmware/link_test` to the Pico; let it send for one to two minutes
   (send `z` for 0 kHz only, or keep the default round-robin of offsets).
2. Log both boards: `python3 analysis/benchlog.py --seconds 120 --out linktest.json`.
3. Run `python3 analysis/linktest_analysis.py linktest.json`. It prints the
   honeypot's mean carrier-offset error.
4. Add that error (in Hz) to `CALIB_HZ` and reflash the honeypot.

A calibrated node reads Doppler-free frames to within ±0.4 kHz.

### Receiver robustness

The receiver configuration and the watchdogs in the sketch each address a
failure seen on the bench; the comments next to the code explain them:

- AFC is required: without it the demodulator only locks on carriers within
  one deviation (5 kHz) of the tuned frequency and silently loses every
  transmitter further out. Raising the deviation instead makes the frequency
  measurement useless.
- The RSSI trigger must be above the noise floor (RadioLib's default of
  −127.5 dBm fires on noise and retunes AFC to nothing).
- The RSSI flag is sticky, so the false-start watchdog uses a window longer
  than one frame (60 ms).
- A supply dip can reset the SX1278 but not the ESP32; `radio_health()`
  checks a configured register once a second and reconfigures the radio.
- Frequency-synthesis RX (`RegOpMode` 0x0C) is the normal idle state of a
  receiver triggered on RSSI, not a fault.
- RadioLib does not check the payload CRC in FSK mode; the firmware reads the
  CRC-OK flag itself.

Porting the method to another SX127x-based receiver means repeating these
checks on that hardware.

## Uplink transmitter

Plays five legitimate stations (`GS100`, `GS102`, `GS104`, `GS107`, `GS109`
at −8, −4, 0, +4 and +8 kHz), each pre-compensating a simulated 10-minute pass
(±6 kHz peak Doppler), and after each of them one attack frame from a
rotating list:

| Attack | Source | Command | Carrier | Tests |
|---|---|---|---|---|
| combined attack | `UNK968` | `REBOOT` | +28 kHz, fixed | frequency, unknown source, command |
| impersonation | `GS104` | `ERASE_FLASH` | 0 kHz, fixed | whitelist, callsign spoof, destructive command |
| probing burst | `UNK971` | `0x7F_UNKNOWN_OPCODE` | +24 kHz, 0.9 s after the previous frame | probing, unknown opcode |
| Doppler spoof | `GS107` | `EPS_STATUS` | +4 kHz, fixed | Doppler mismatch only |
| malformed frame | `GS102` | `HK_DUMP` | −4 kHz, tracking | malformed packet only (AX.25 FCS broken) |

Each frame is logged as one line on USB serial:

```
[up] t= 24.3s GS104  -> HNY1  PING                 foff= +0.0 kHz  dop= +5965 Hz  legit            sent
[up] t= 29.3s UNK971 -> HNY1  0x7F_UNKNOWN_OPCODE  foff=+24.0 kHz  dop=    +0 Hz  probing burst    sent
```

## Link test

Sends `LNKTST` frames with a sequence number at a fixed interval, cycling the
carrier offset through 0, −8, +8, −4, +4, +24 and +28 kHz. Serial commands:
`r` round-robin offsets (default), `z` 0 kHz only, `1`–`9` interval in
hundreds of milliseconds (default 500 ms). Each frame is logged as one
`[lt] ...` line.

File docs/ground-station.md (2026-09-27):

# CTI ground station

The ground station is a Raspberry Pi 4 with a Ra-01 radio on its SPI bus. Two
programs run on it:

- `ground_station/receiver/`: **cti_receiver**, a small C++ program (RadioLib
  over lgpio) that receives the honeypot's downlink and prints one
  `CTI,<csv>` line per record;
- `ground_station/server/`: **hny_server.py**, which starts the receiver,
  stores the records in SQLite, runs the ground analysis and serves the
  threat-intelligence portal on port 8700.

The server needs only the Python standard library. The portal also runs
without any hardware in simulation mode.

## Setup

On Raspberry Pi OS (64-bit recommended):

```sh
sudo apt install git cmake g++ liblgpio-dev python3
sudo raspi-config nonint do_spi 0        # enable SPI; /dev/spidev0.0 must appear
sudo usermod -aG spi,gpio "$USER"        # log out and in again afterwards

git clone https://github.com/Jamil-Jafarli/cti_cubesat.git ~/cti_cubesat
cd ~/cti_cubesat/ground_station/receiver
./build.sh                               # fetches RadioLib 7.7.1, builds build/cti_receiver
```

Wire the Ra-01 as described in [hardware.md](hardware.md#cti-ground-station-ra-01--raspberry-pi-4).

## Running

```sh
cd ~/cti_cubesat/ground_station/server
python3 hny_server.py --radio --host 0.0.0.0
```

Open `http://<pi-address>:8700` from any machine on the network. The receiver
measures the noise floor when it starts and sets its trigger 15 dB above it.
Every minute it prints an `alive` line with its counters and the RSSI range
it saw, so a silent radio is easy to spot in the log.

| Option | Meaning |
|---|---|
| `--radio [BIN]` | start the Pi receiver (default `../receiver/build/cti_receiver`) and read its records |
| `--serial PORT` | read `CTI,<csv>` lines from a receiver on a serial port instead (needs pyserial) |
| `--simulate` | no hardware: fill the portal from the synthetic pipeline in `simulation/` |
| `--n N` | number of simulated packets (default 150) |
| `--rssi-threshold DBM` | fixed receiver trigger level instead of floor + 15 dB |
| `--host`, `--port` | portal address (default 127.0.0.1:8700); use `--host 0.0.0.0` for the LAN |
| `--reset` | delete the database before starting |
| `--analyse` | re-run the ground analysis over the stored records and exit |

The database is `ground_station/server/bench_cti.db`. When the downlink goes
quiet for two seconds, the server runs the ground analysis
([detection.md](detection.md#ground-analysis)) over what arrived.

### Simulation mode

```sh
pip install -r simulation/requirements.txt
cd ground_station/server
python3 hny_server.py --simulate --reset
```

This fills the portal with the 150-packet synthetic dataset, so the portal
and the API can be explored without any radio.

### Start at boot (systemd)

Edit `User`, `Group` and `WorkingDirectory` in
`ground_station/server/cti-server.service` for your Pi, then:

```sh
sudo cp ground_station/server/cti-server.service /etc/systemd/system/
sudo systemctl daemon-reload
sudo systemctl enable --now cti-server
journalctl -u cti-server -f
```

`KillMode=control-group` stops the receiver together with the server, so SPI
and the GPIO lines are released on restart.

## The portal

Portal overview

| View | Shows |
|---|---|
| Overview | traffic over time (flagged frames on top), open alerts by severity, sources by risk, latest detections |
| Alerts | the alert queue with filters; each alert shows its evidence and the onboard fuzzy match term by term; open → acknowledged → closed |
| Telemetry | every stored frame with its RF metadata, onboard and ground scores |
| Attribution | source profiles with risk, first and last seen, commands and signatures |
| Indicators | callsigns, transmitter signatures and commands with confidence, TLP and disposition; export as STIX 2.1, MISP or CSV |
| Onboard policy | the allowlist and blocklist the satellite enforces next to what the ground now proposes, and the difference |

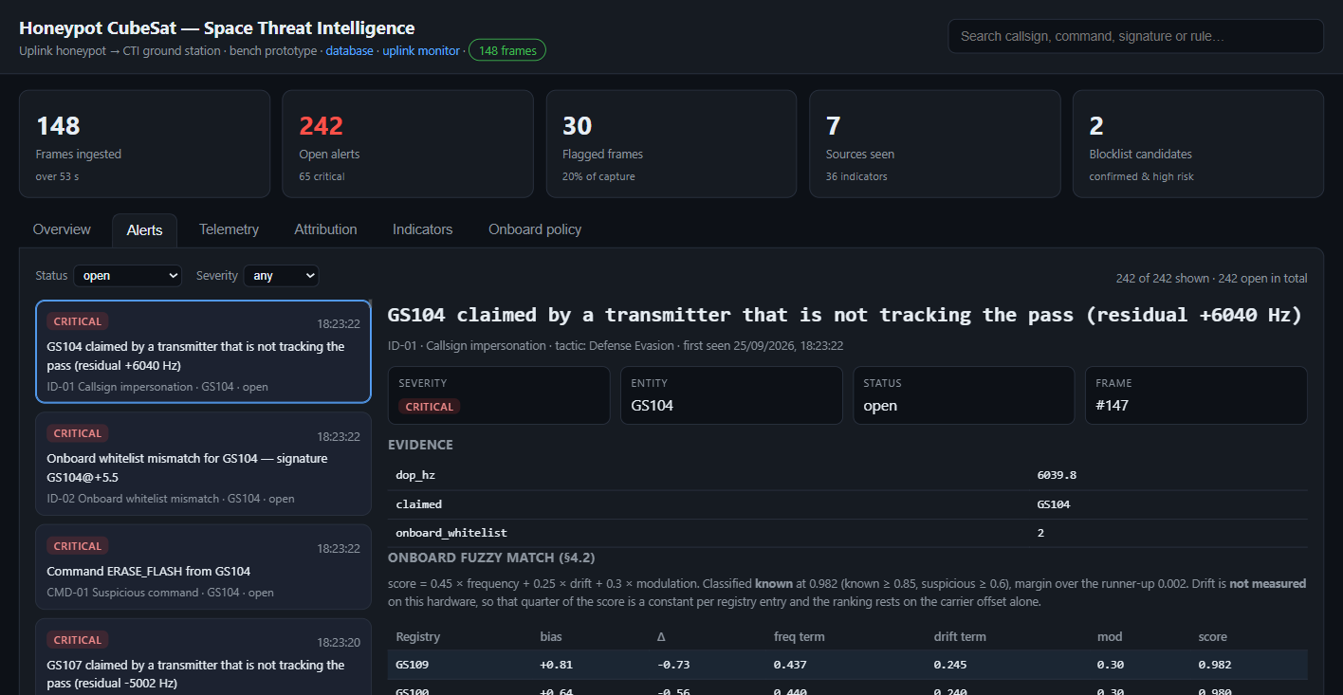
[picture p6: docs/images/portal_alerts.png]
Alerts


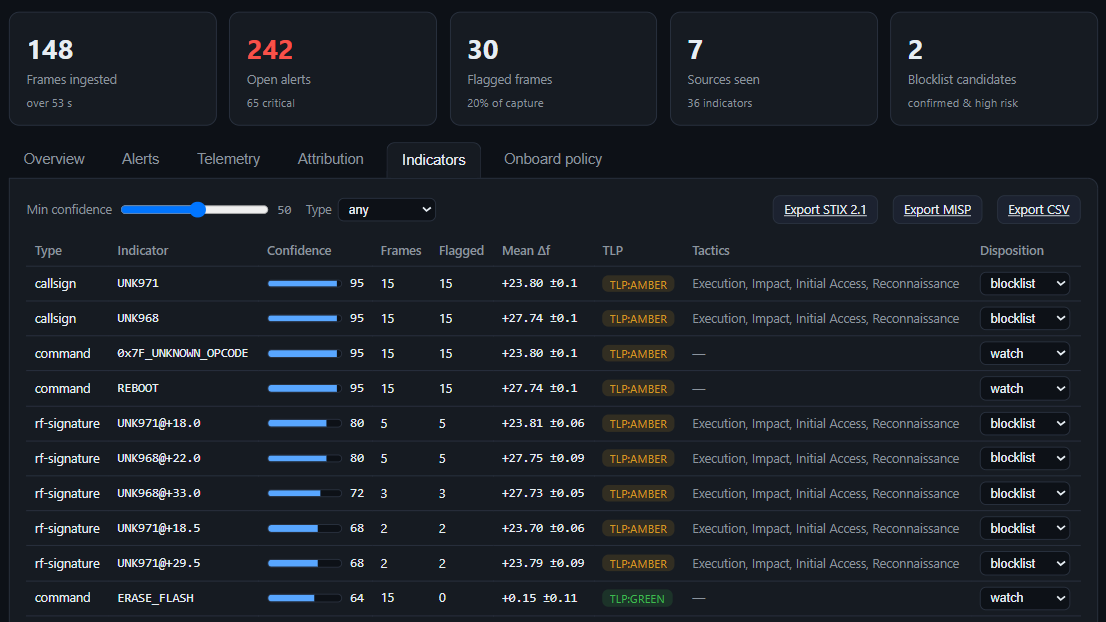
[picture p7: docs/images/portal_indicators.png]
Indicators


A separate database page (`/db.html`) lists, edits and deletes stored records.

## HTTP API

All responses are JSON unless noted.

| Method | Path | Returns / does |
|---|---|---|
| GET | `/api/state` | KPIs, the latest 200 frames and the source profiles |
| GET | `/api/packets` | stored records |
| GET | `/api/alerts?status=open` | alert queue (`open`, `ack`, `closed` or `all`) |
| GET | `/api/indicators` | indicator set with confidence, TLP and disposition |
| GET | `/api/attribution` | source profiles |
| GET | `/api/timeseries` | traffic per interval |
| GET | `/api/policy` | onboard lists vs ground proposal |
| GET | `/api/analysis/<id>` | full analysis of one record, including the fuzzy-match breakdown |
| GET | `/api/export/stix?min_confidence=50` | STIX 2.1 bundle |
| GET | `/api/export/misp?min_confidence=50` | MISP event |
| GET | `/api/export/csv` | indicators as CSV |
| POST | `/api/analyse` | re-run the ground analysis |
| POST | `/api/alert/<id>` | change an alert's status, body `{"status": "open" \| "ack" \| "closed"}` |
| POST | `/api/indicator` | set a disposition, body `{"value": ..., "status": "watch" \| "blocklist" \| "allowlist" \| "dismissed", "note": ...}` |
| POST | `/api/packet/<id>` | edit a record |
| DELETE | `/api/packet/<id>` | delete a record |
| POST | `/api/reset` | empty the database |

The API has no authentication. Keep the portal on a trusted network.

## Log output

The receiver's lines are echoed by the server. From the 2026-09-25 campaign
downlink:

```
[server] stored: GS104 ERASE_FLASH onboard_score=15 known
[server] stored: GS104 PING onboard_score=0 known
[server] stored: UNK971 0x7F_UNKNOWN_OPCODE onboard_score=70 attacker
[gs] alive rx=148 cti=148 dropped=0 ignored=0 restarts=0 stuck=0 reinit=0 rssi_min=-101 rssi_max=-49
```

| Line | Meaning |
|---|---|
| `[gs] ok — listening ...` | receiver ready, with the measured noise floor and trigger level |
| `CTI,<csv>` | one downlinked record (stored by the server and echoed as `[server] stored: ...`) |
| `[gs] frame dropped: ...` | PHY CRC or AX.25 FCS failed |
| `[gs] ignoring frame SRC -> DST ... info=...` | a frame that is not part of the downlink, logged in full with its carrier offset; this makes the ground station a reference receiver for link tests |
| `[gs] alive ...` | counters every minute: frames received, records, drops, ignored frames, watchdog restarts, RSSI range |

## Troubleshooting

| Symptom | Check |
|---|---|
| `radio init FAILED, code -2` | wiring (MISO, SCK, NSS), 3.3 V at the module, SPI enabled |
| receiver starts, but nothing arrives | antennas, both nodes on 433.5 MHz, the honeypot's `D` command; the `alive` line's `rssi_max` shows whether anything is heard |
| `frame dropped: PHY CRC failed` | weak or disturbed link: move the boards, check the antennas and the decoupling capacitors |
| `Permission denied` on SPI or GPIO | add the user to the `spi` and `gpio` groups, or run the systemd service |

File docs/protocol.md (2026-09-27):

# Radio link and data formats

## Radio channel

| Parameter | Value |
|---|---|
| Frequency | 433.5 MHz (ISM band) |
| Modulation | 2-FSK, no Gaussian shaping (RadioLib `beginFSK`) |
| Bit rate | 9.6 kb/s |
| Frequency deviation | 5 kHz |
| Receiver bandwidth | 58.6 kHz |
| AFC bandwidth | 83.3 kHz (receivers), started on the RSSI interrupt |
| Preamble | 64 bits |
| Sync word | RadioLib default |
| PHY CRC | on (CRC-16, checked in firmware, see below) |
| Output power | 2 dBm |
| Range on the bench | 1–2 m |

The flight concept uses the 435–438 MHz amateur-satellite band, which needs a
licence to transmit. The bench therefore runs in the ISM band at minimum power.
Every indicator is computed relative to the node's own centre frequency, so
the change of band does not affect the detection.

The receivers measure each frame's carrier offset from the SX1278's AFC
register (`RegAfcValue`, step 32 MHz / 2¹⁹ ≈ 61 Hz). RadioLib 7.7.1 does not
check the payload CRC in FSK mode, so the firmware reads the CRC-OK flag from
`RegIrqFlags2` before reading the FIFO and drops frames that fail it.

## AX.25 UI frame

Every frame on the air is an AX.25 UI frame inside one SX1278 packet:

```
┌─ SX1278 packet engine ────────────────────────────────────────────────────┐
│ preamble │ sync word │ length │           AX.25 UI frame           │ CRC  │
└──────────┴───────────┴────────┴────────────────────────────────────┴──────┘
                                   │
     ┌─────────────────────────────┘
     ▼
┌──────────────┬──────────────┬─────────┬──────┬─────────────┬────────┐
│ destination  │ source       │ control │ PID  │ info        │ FCS    │
│ 7 bytes      │ 7 bytes      │ 0x03    │ 0xF0 │ 0–46 bytes  │ 2 bytes│
└──────────────┴──────────────┴─────────┴──────┴─────────────┴────────┘
```

- **Addresses:** six callsign characters, each shifted left by one bit and
  padded with spaces, followed by an SSID byte (`0x60 | ssid << 1`; the last
  address sets bit 0). Callsigns carry no dash.
- **Control / PID:** `0x03` (UI frame, no connection) and `0xF0` (no layer 3).
- **FCS:** CRC-16/X.25 (polynomial 0x1021 reflected, init and xorout 0xFFFF),
  low byte first.

The AX.25 header is 18 bytes. The SX1278's FSK FIFO holds 64 bytes, so the
info field of a single frame is limited to 46 bytes.

The honeypot decodes frames even when the AX.25 FCS fails (the frame is then
recorded with `crc_ok = 0`, which the malformed-packet indicator uses); the
ground station rejects them.

## Frame types

| Direction | Source → destination | Info field |
|---|---|---|
| Uplink (scenario) | `GS100`…`GS109`, `UNK968`, `UNK971` → `HNY1` | `"<seq>|<command>"`, e.g. `"42|REBOOT"` |
| Uplink (link test) | `LNKTST` → `HNY1` | `"<seq>|O<offset>S<seq>"`, e.g. `"123|O+24S0123"` |
| Downlink | `HNY1` → `CTIGS` | one packed `RecordWire` (42 bytes) |

On the bench the commands are ASCII strings. A real mission would use binary
telecommands (for example CCSDS/PUS service numbers or CSP ports), and the
command classification would then need that mission's command dictionary.

## CTI record

The honeypot stores one fixed-size `Record` per frame in LittleFS
(`/records2.bin`, appended):

| Field | Type | Meaning |
|---|---|---|
| `t_ms` | uint32 | `millis()` at reception |
| `src` | char[10] | claimed source callsign |
| `cmd` | char[20] | command (info field after `|`) |
| `freq_dev_khz` | float | carrier offset, calibrated |
| `dop_hz` | float | Doppler residual from the onboard estimate |
| `rssi` | float | dBm |
| `crc_ok` | uint8 | AX.25 FCS valid |
| `gap_s` | float | seconds since the previous frame |
| `score` | uint8 | anomaly score 0–100 |
| `fuzzy` | float | best fuzzy-match score 0–1 |
| `cls` | char[12] | `known`, `suspicious` or `attacker` |
| `flagged` | uint8 | `score ≥ 50` |
| `conf` | float | confidence, `min(89.15, 42 + 0.53 × score)` |
| `fp` | char[21] | record identifier: first 10 bytes of SHA-256, hex |
| `sig` | char[18] | transmitter signature, e.g. `GS104@+0.0` |
| `wl` | uint8 | whitelist state: 0 none, 1 match, 2 mismatch |

## Downlink record (`RecordWire`)

A CSV record would be about 104 bytes, too long for one frame, so records
are downlinked packed (42 bytes, 60 bytes on the air with AX.25):

| Field | Type | Unit |
|---|---|---|
| `t_ms` | uint32 | ms |
| `src` | char[7] | callsign |
| `cmd` | char[20] | command |
| `dev_dahz` | int16 | carrier offset, 10 Hz |
| `res_dahz` | int16 | offset with the common-mode Doppler removed, 10 Hz |
| `dop_dahz` | int16 | Doppler residual, 10 Hz |
| `rssi_dbm` | int8 | dBm |
| `gap_ds` | uint8 | 0.1 s, saturating at 25.5 s |
| `fuzzy_x100` | uint8 | fuzzy score × 100 |
| `score` | uint8 | anomaly score |
| `flags` | uint8 | bit 0 `crc_ok`, bit 1 `flagged`, bits 2–3 whitelist state |

The class, confidence and signature are derived again on the ground, and the
SHA-256 identifier is not sent: the ground assigns its own.

The honeypot sends one record every 300 ms. The ground station re-arms AFC
and AGC after every frame and needs the gap to recover from a false start.

## Receiver output line

The CTI receiver expands every downlink record into one line on stdout, which
the server stores:

```
CTI,<t_ms>,<src>,<cmd>,<freq_dev_khz>,<dop_hz>,<rssi>,<crc_ok>,<gap_s>,<score>,<fuzzy>,<cls>,<flagged>,<conf>,<fp>,<sig>,<wl>
```

`fp` is empty in downlinked records; the server fills in its own identifier.
The server also accepts the 14-field form without `sig` and `wl`.

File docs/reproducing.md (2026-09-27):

# Reproducing the measurements

`data/2026-09-25-campaign/` holds the raw logs and the ground database of the
bench campaign of 25 September 2026. The scripts in `analysis/` turn them into
the published figures, and the same scripts work on your own logs.

The analysis scripts need Python 3.9+ and nothing else; only the logger
(`benchlog.py`) needs pyserial.

## From the bundled data

```sh
cd analysis
D=../data/2026-09-25-campaign

python3 scenario_analysis.py $D/scenario_run.json $D/ground.db
python3 member_analysis.py   $D/member_run.json
python3 linktest_analysis.py $D/linktest_900ms.json
python3 linktest_analysis.py $D/linktest_500ms.json
```

### End-to-end scenario run

A 15-minute run of `firmware/uplink_transmitter`. The honeypot started with an
empty store and the ground station with an empty database; afterwards the
transmitter was silenced and the honeypot downlinked its 148 stored records
(all 148 arrived without a CRC error, in each of two passes). Every ground
record is matched to the frame the transmitter logged, by callsign, command
and time.

```
transmitted 147, captured 128 (87.1%), ground records 148 (20 outside the logged window)
capture per 3 minutes: 32/32, 30/30, 31/32, 26/26, 9/27
scenario            captured  onboard flag  wl mismatch  malformed  ground flag
legit                63/72               0            3          0            0
freq+unknown+cmd     13/15              13            0          0           13
callsign spoof       14/16               0           12          0            0
probing burst        14/16              14            0          0           14
doppler spoof        12/13               0            0          0            0
malformed FCS        12/15               0            0         12            0
carrier-offset error, Doppler-free frames: -0.06 ± 0.20 kHz, 53/53 within ±0.4 kHz
alerts per scenario:
  legit              {"REC-02/medium": 13, "ID-02/critical": 3}
  freq+unknown+cmd   {"RF-01/high": 13, "RF-02/high": 13, "CMD-01/medium": 13, "REC-01/medium": 13}
  callsign spoof     {"RF-02/high": 14, "ID-01/critical": 14, "CMD-01/critical": 14, "ID-02/critical": 12}
  probing burst      {"RF-01/high": 14, "RF-02/high": 14, "CMD-01/medium": 14, "REC-01/medium": 14}
  doppler spoof      {"RF-02/high": 12, "ID-01/critical": 12}
  malformed FCS      {"INT-01/low": 12}
  other / aggregate  {...}
```

Reading it:

- Every attack record raised at least one alert, and the impersonations raised
  critical ones. No legitimate record was flagged.
- The score threshold (50) separates only the combined attacks; the
  single-indicator attacks are caught by the ground rules.
- The remaining alerts on legitimate records come from the indicator
  definitions: a 0.9 s burst is attributed to the frame after it (REC-02), and
  the onboard Doppler estimate lags the fastest part of the pass (three
  whitelist mismatches, ID-02).
- Capture was 119 of 120 frames for the first 12 minutes. In the last three
  minutes the bench was physically disturbed and capture fell to 9 of 27.
- "other / aggregate" holds the records outside the logged window and the two
  AGG-01 campaign alerts.

### Member mode

A 6-minute run with the honeypot in member mode (`M`), after the disturbance:
39 of 61 frames were heard. All 11 frames heard from blocklisted sources were
blocked, including the `GS104 ERASE_FLASH` impersonation (whitelist mismatch,
so the allowlist override was withheld). 22 of 23 legitimate frames were
accepted; the exception is one real `GS104 PING` whose estimated residual fell
outside the whitelist tolerance, the bench's one false block. The Doppler
spoof and the malformed frames were accepted, as they must be in a mode that
blocks only on the blocklist.

### Link test

`firmware/link_test` at seven carrier offsets, logged frame by frame:

| Frame interval | Honeypot | Honeypot carrier-offset error |
|---|---|---|
| 0.9 s | 75 of 77 (97 %) | −0.00 ± 0.24 kHz |
| 0.5 s | 22 of 247 (9 %) | +0.11 ± 2.34 kHz |

The ground station, logging the same frames as a reference receiver, decoded
all of them at both intervals (its log is not included). The honeypot
scores, fingerprints and writes each frame to flash (up to 154 ms) before it
listens again, so it cannot keep up with frames about twice a second.

### Processing time and power

`honeypot_status.json` is the honeypot's status report after the scenario run
(134 frames processed by then), `power.json` three runs of the power profile:

| Quantity | Value |
|---|---|
| scoring + fingerprint per frame, mean / max | 290 µs / 347 µs (x86_64 desktop: 195 µs) |
| flash write per frame, mean / max | 44.7 ms / 154 ms |
| worst heap change during processing | −44 B |
| lowest free heap | 328 kB |
| deepest stack use | 4,684 B |
| radio, receiving | 15.8 mA, 52.4 mW at 3.30 V |
| radio, standby | 2.2 mA |
| radio, 2 dBm transmit | 69.2 mA, 228 mW |
| radio, sleep | below the INA219's 0.1 mA resolution |

The power figures are the radio's own supply (the INA219 sits between the
regulator and the Ra-01); the ESP32, its regulator and the USB bridge are
not included.

## On your own bench

1. **Link test and calibration.** Flash `firmware/link_test`, then log both
   boards for two minutes and analyse:

   ```sh
   python3 benchlog.py --seconds 120 --out linktest.json
   python3 linktest_analysis.py linktest.json
   # optional: the ground station's view of the same frames
   journalctl -u cti-server --since "<start time>" -q > gs.log
   python3 linktest_analysis.py linktest.json --gs-log gs.log
   ```

   Add a steady mean error to `CALIB_HZ` (see [firmware.md](firmware.md#calibration)).

2. **Radio power.** With every transmitter silent, send `P` to the honeypot
   (three times for repeatability).

3. **Scenario run.** Flash `firmware/uplink_transmitter`. Erase the
   honeypot's store (`E`) and start the server with an empty database
   (`--reset`). Then:

   ```sh
   python3 benchlog.py --seconds 900 --out run.json --node-cmd R   # 15 min, resets the timing counters
   # silence the transmitter, send D to the honeypot, wait for "[dl] done"
   # copy ground_station/server/bench_cti.db from the Pi to ground.db
   python3 scenario_analysis.py run.json ground.db
   ```

   Send `S` to the honeypot after the run for the processing-time figures.

4. **Member mode.**

   ```sh
   python3 benchlog.py --seconds 360 --out member.json --node-cmd M
   python3 member_analysis.py member.json
   # send M again to return the node to honeypot mode
   ```

`benchlog.py` finds the Pico on `/dev/ttyACM*` and expects the honeypot on
`/dev/ttyUSB0`; use `--pico` and `--node` for other ports. Its output is
`{"pico": [[t, line], ...], "node": [[t, line], ...]}` with host timestamps;
the bundled logs use the key `esp` for the honeypot, which the scripts accept
as well.

## Synthetic evaluation

The detection pipeline was first checked on a labelled synthetic dataset
(150 uplink packets, 32 of them with injected anomalies):

```sh
cd simulation
pip install -r requirements.txt
python3 export.py
```

```
packets                : 150
malicious (ground truth): 32
detections             : 32  (TP=32 FP=0 FN=0 TN=118)
detection rate         : 1.000
false positive rate    : 0.000
```

The generator injects anomalies along the same features the detector scores,
so this confirms that the pipeline is internally consistent. It is not
evidence of performance against a real, adaptive attacker.

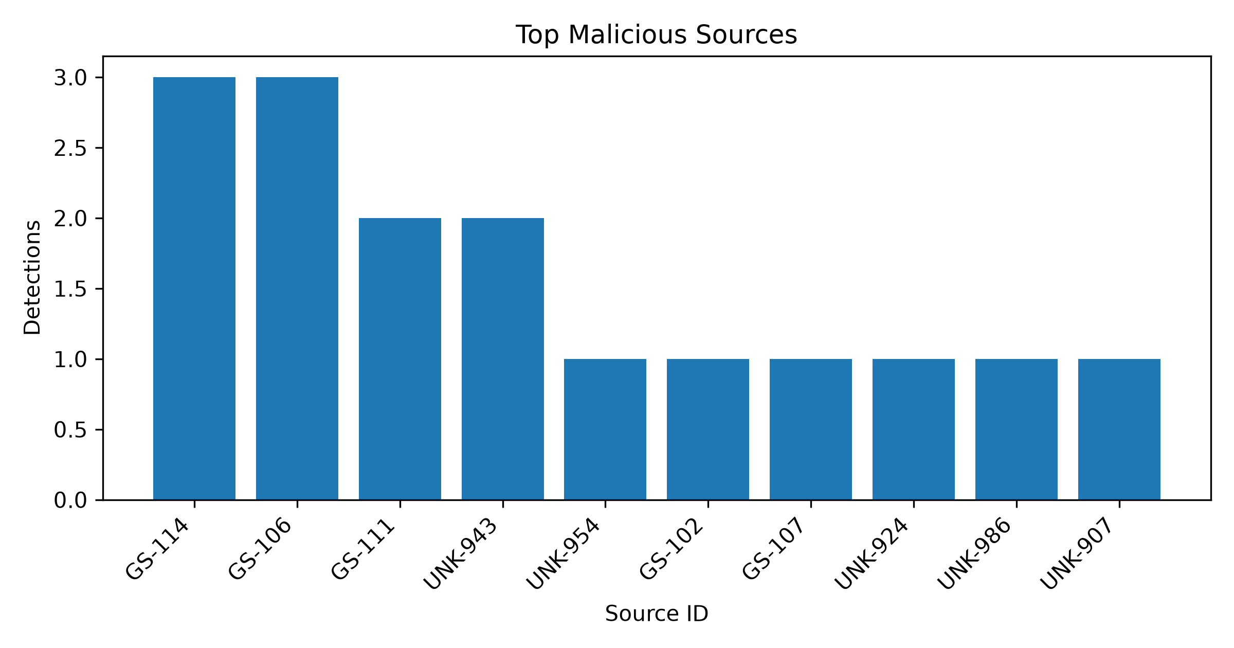
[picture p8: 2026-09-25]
docs/images/simulation_sources.png

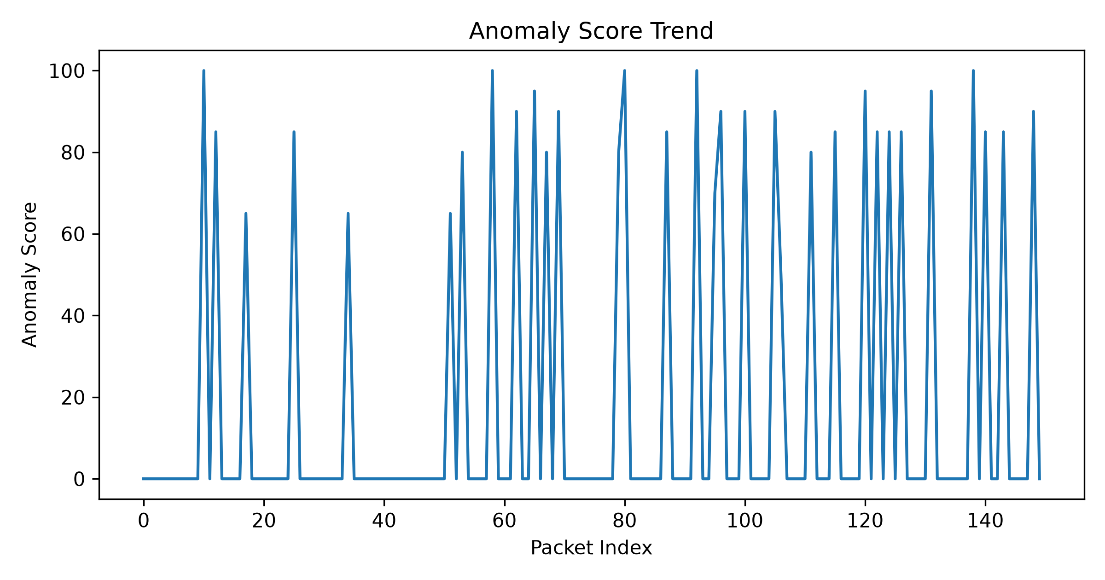
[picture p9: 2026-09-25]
docs/images/simulation_anomaly.png

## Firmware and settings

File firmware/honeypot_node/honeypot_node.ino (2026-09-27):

/* ═══════════════════════════════════════════════════════════════════════════
   Honeypot node — ESP32 + SX1278 (Ai-Thinker Ra-01)

   The bench stand-in for the honeypot CubeSat's detection board. It listens
   to the uplink, and for every AX.25 frame it receives it:

     1. measures the RF metadata (carrier offset from the SX1278 AFC, RSSI,
        time since the previous frame),
     2. scores the frame with the seven-indicator anomaly score and the fuzzy
        transmitter match (HnyProto.h, the same math as simulation/detector.py),
     3. checks the transmitter against the fingerprint whitelist,
     4. appends a fixed-size CTI record to on-board flash (LittleFS).

   On command it downlinks every stored record to the CTI ground station as
   AX.25 UI frames HNY1 -> CTIGS. In member mode the board acts instead as the
   accept/block gate a member satellite would run: it prints a verdict and
   stores nothing.

   Hardware
     ESP32-WROOM-32D development board ("ESP32 Dev Module")
     Ai-Thinker Ra-01 (SX1278) receiver, powered through an INA219 shunt
     INA219 current monitor on the radio's 3.3 V line
     four verdict LEDs

   Wiring
     Ra-01  SCK  -> IO18    MISO -> IO19    MOSI -> IO23    NSS  -> IO5
            RESET -> IO14   DIO0 -> IO26    GND  -> GND
            3.3V -> INA219 VIN-   (INA219 VIN+ -> ESP32 3V3)
     INA219 VCC -> 3V3      GND -> GND      SDA -> IO21     SCL -> IO22
     LEDs   red IO32 (300 R), amber IO17 (200 R), green IO16 (300 R),
            blue IO4 (200 R); cathodes to GND
     IO0    BOOT button: starts a downlink
     IO25   optional COM_TX_ACTIVE input, active low (internal pull-up)

   Build
     Board "ESP32 Dev Module" (esp32 core 2.0.17), a partition scheme with a
     SPIFFS/LittleFS area, libraries RadioLib 7.7.1 and HnyProto.

   Serial commands (115200 baud, one character)
     D  downlink all stored records (the BOOT button does the same)
     S  status JSON: store, receiver counters, timing, heap and stack
     E  erase the record store
     R  reset the timing counters
     M  toggle honeypot / member mode
     F  print the fingerprint whitelist
     A  enrol the transmitter of the last received frame
     X  clear the whitelist
     P  radio power profile via the INA219
     Q  in-band RSSI scan, 433.40-433.60 MHz (run with all transmitters off)

   Output lines
     [rx]  one scored frame (honeypot mode)      [mbr] one verdict (member mode)
     [dl]  downlink progress                     [wl]  whitelist
     [hny] node events                           [scan] band scan
     {"evt":"status",...}, {"evt":"power",...}   machine-readable reports
   ═══════════════════════════════════════════════════════════════════════════ */
#include <RadioLib.h>
#include <LittleFS.h>
#include <mbedtls/sha256.h>
#include <freertos/FreeRTOS.h>
#include <freertos/task.h>
#include <HnyProto.h>
#include <Wire.h>
#include <algorithm>

/* ── pins ─────────────────────────────────────────────────────────────── */
#define PIN_SCK 18
#define PIN_MISO 19
#define PIN_MOSI 23
#define PIN_NSS 5
#define PIN_RST 14
#define PIN_DIO0 26
#define PIN_LED 32             // red   — flagged or attacker
#define PIN_LED_G 16           // green — known ground station
#define PIN_LED_Y 17           // amber — suspicious
#define PIN_LED_B 4            // blue  — downlink in progress
#define PIN_BOOT 0
#define PIN_SDA 21             // INA219
#define PIN_SCL 22

/* COM_TX_ACTIVE: the satellite's main radio asserts this line while it
   transmits. That transmitter sits centimetres away in the same band at watt
   level, far above this receiver's maximum input, so the receiver is parked
   for the whole transmission. Active low with the internal pull-up: an
   unconnected pin reads "not transmitting". Flip TX_ACTIVE_LEVEL for a radio
   that drives the line high.                                                */
#define PIN_TX_ACTIVE 25
#define TX_ACTIVE_LEVEL LOW

/* ── radio ────────────────────────────────────────────────────────────── */
static Module *radioMod = new Module(PIN_NSS, PIN_DIO0, PIN_RST, RADIOLIB_NC);
SX1278 radio = radioMod;       // radioMod is kept for raw register access

static const float CENTER_MHZ = 433.5f;

/* Crystal offset between this receiver and the transmitter, subtracted from
   every carrier measurement. Measured with firmware/link_test on Doppler-free
   frames (analysis/linktest_analysis.py). It is a property of the module
   pair, not of the design: re-measure whenever a radio module is replaced or
   reworked.                                                                  */
static const float CALIB_HZ   = 2730.0f;

/* RSSI level that starts each AFC/AGC cycle. It must sit above the noise
   floor, or noise keeps restarting AFC, and not too far below the frames, or
   AGC is set on the transmitter's power ramp instead of the settled carrier.
   It starts at floor + FLOOR_MARGIN_DB (floor measured at boot) and then
   follows the received frames at their average RSSI - FRAME_MARGIN_DB,
   never below the floor limit.                                               */
static const float FLOOR_MARGIN_DB = 15.0f;
static const float FRAME_MARGIN_DB = 30.0f;
static float rssiTrigDbm = -75.0f;      // replaced at boot, then tracks the frames
static float rssiFloorDbm = NAN;
static float frameRssiAvg = NAN;        // exponential average of received frames

/* ── storage ──────────────────────────────────────────────────────────── */
// The store is versioned by file name: a file written with an older Record
// layout has a different stride, so it is deleted at boot instead of read.
static const char *STORE = "/records2.bin";
static const char *STORE_LEGACY = "/records.bin";
static const char *FP_STORE = "/fpallow.csv";

/* ── fingerprint whitelist ────────────────────────────────────────────── */
#define FP_MAX 8
static FpAllow fpAllow[FP_MAX];
static size_t  nFpAllow = 0;
static const float FP_ENROL_TOL_KHZ = 1.5f;   // temperature and ageing margin,
                                              // applied to the Doppler-free residual

// the last frame heard, so that 'A' can enrol its transmitter
static char  lastSrc[10] = {0};
static float lastDevKhz   = 0.0f;
static float lastResidKhz = 0.0f;
static bool  haveLastPkt = false;

/* ── common-mode Doppler estimate ─────────────────────────────────────── */
#define DOP_WIN 8
#define DOP_MIN_N 3
static float    dopWin[DOP_WIN];
static uint8_t  dopN = 0, dopI = 0;
static float    dopEstKhz = 0.0f;

/* ── board mode ───────────────────────────────────────────────────────── */
/* HONEYPOT scores, stores and later downlinks every frame. MEMBER is the
   gate a member satellite runs: it answers with an accept/block verdict from
   the CTI lists and stores nothing.                                         */
enum Mode : uint8_t { MODE_HONEYPOT = 0, MODE_MEMBER = 1 };
static Mode mode = MODE_HONEYPOT;

static const char *mode_name() {
  return mode == MODE_MEMBER ? "member" : "honeypot";
}

/* ── receiver state and counters (reported by 'S') ────────────────────── */
volatile bool rxFlag = false;
static uint32_t rxRaw = 0;       // every RxDone, decodable or not
static uint32_t rxStuck = 0;     // receiver restarts after a sync match that never completed
static uint32_t radioReinit = 0; // radio found at its reset defaults and reconfigured
static uint32_t rxModeFix = 0;   // radio found in standby or sleep, receiver restarted
static uint32_t rxCrcBad = 0;    // frames that failed the PHY CRC, dropped
static uint32_t rxPolled = 0;    // frames found by polling PayloadReady (no DIO0 edge)
void IRAM_ATTR onRx() { rxFlag = true; }
static uint32_t lastRxMs = 0;
static bool haveLast = false;
static uint32_t nStored = 0;
static bool     rxBlanked   = false;   // receiver parked while COM transmits
static uint32_t blankT0Ms   = 0;       // start of the current blanking window
static uint32_t blankN      = 0;       // blanking windows since boot
static uint32_t blankMsTotal = 0;      // total blanked time

/* Processing-time instrumentation. Scoring and the flash write are timed
   separately: the LittleFS write is one to two orders of magnitude slower
   and depends on the state of the flash, not on the algorithm.             */
struct Perf {
  uint32_t n;                            // frames measured
  uint32_t score_sum_us, score_max_us;   // hny_score() + fingerprint()
  uint32_t store_sum_us, store_max_us;   // store_record(), flash
  int32_t  heap_delta_min;               // most negative free-heap change seen
};
static Perf perf = {0, 0, 0, 0, 0, 0};

static inline void perf_add(uint32_t score_us, uint32_t store_us, int32_t heap_delta) {
  perf.n++;
  perf.score_sum_us += score_us;
  perf.store_sum_us += store_us;
  if (score_us > perf.score_max_us) perf.score_max_us = score_us;
  if (store_us > perf.store_max_us) perf.store_max_us = store_us;
  if (heap_delta < perf.heap_delta_min) perf.heap_delta_min = heap_delta;
}

/* ═══════════════════════════ radio configuration ═════════════════════════ */

/* Full receiver configuration. Applied at boot and again whenever the radio
   is found back at its reset defaults (radio_health()).                    */
static int radio_config() {
  // 2-FSK, 9.6 kb/s, 5 kHz deviation, 58.6 kHz RX bandwidth, 2 dBm and a
  // 64-bit preamble, so that AGC and AFC can settle before the sync word.
  // Identical on every node of the bench.
  int st = radio.beginFSK(CENTER_MHZ, 9.6, 5.0, 58.6, 2, 64);
  if (st != RADIOLIB_ERR_NONE) return st;
  radio.setCRC(true);
  // AFC. Without it the demodulator only locks on carriers within about one
  // deviation (5 kHz) of the tuned frequency, and every source further out is
  // lost without a trace. With AFC the chip measures the carrier in a wide
  // AFC bandwidth at the start of each reception and retunes to it, and the
  // applied correction is the carrier offset reported per frame.
  //  - 83.3 kHz AFC bandwidth covers the +28 kHz test attacker plus the
  //    crystal offset and the signal's own bandwidth.
  //  - AFC starts on the RSSI interrupt: a carrier far off-tune cannot be
  //    demodulated, so its preamble is never detected before AFC pulls it in.
  //  - The RSSI threshold must be above the noise floor (RadioLib's default
  //    of -127.5 dBm fires on noise), see rssiTrigDbm.
  //  - AfcAutoClearOn: every frame is measured from the nominal centre, not
  //    from the previous transmitter's offset.
  radio.setAFCBandwidth(83.3);
  radio.setAFC(true);
  radio.setAFCAGCTrigger(RADIOLIB_SX127X_RX_TRIGGER_RSSI_INTERRUPT);
  radio.setRSSIThreshold(rssiTrigDbm);
  radioMod->SPIsetRegValue(RADIOLIB_SX127X_REG_AFC_FEI, RADIOLIB_SX127X_AFC_AUTO_CLEAR_ON, 0, 0);
  // 2-byte preamble detector, as on the ground station.
  radioMod->SPIsetRegValue(RADIOLIB_SX127X_REG_PREAMBLE_DETECT,
      RADIOLIB_SX127X_PREAMBLE_DETECTOR_ON | RADIOLIB_SX127X_PREAMBLE_DETECTOR_2_BYTE |
      RADIOLIB_SX127X_PREAMBLE_DETECTOR_TOL);
  // Keep CRC-failed frames in the FIFO (CrcAutoClearOff) so that
  // handle_uplink() can count them (crc_bad) instead of losing them silently
  // inside the chip. A frame lost to bit errors is then told apart from one
  // that never synchronised.
  radioMod->SPIsetRegValue(RADIOLIB_SX127X_REG_PACKET_CONFIG_1,
      RADIOLIB_SX127X_CRC_AUTOCLEAR_OFF, 3, 3);
  radio.setDio0Action(onRx, RISING);
  return radio.startReceive();
}

/* Move the RSSI trigger with the received frames (see rssiTrigDbm). */
static void track_frame_rssi(float rssi) {
  frameRssiAvg = std::isnan(frameRssiAvg) ? rssi : 0.8f * frameRssiAvg + 0.2f * rssi;
  float want = std::max(rssiFloorDbm + FLOOR_MARGIN_DB, frameRssiAvg - FRAME_MARGIN_DB);
  want = std::min(-60.0f, std::max(-100.0f, want));
  if (fabsf(want - rssiTrigDbm) < 3.0f) return;   // no churn on small changes
  rssiTrigDbm = want;
  radio.setRSSIThreshold(rssiTrigDbm);
  radio.startReceive();
}

/* Carrier offset of the frame just received: RegAfcValue, the correction the
   chip applied at the start of this reception (signed 16 bit, step
   32 MHz / 2^19). The FEI register is not added: read after RxDone it
   averages payload bits and scatters by several kHz.                        */
static float carrier_offset_hz() {
  int16_t afc = (int16_t)((radioMod->SPIreadRegister(RADIOLIB_SX127X_REG_AFC_MSB) << 8) |
                           radioMod->SPIreadRegister(RADIOLIB_SX127X_REG_AFC_LSB));
  const float FSTEP = 32000000.0f / 524288.0f;
  return afc * FSTEP;
}

/* ═══════════════════════════ fingerprint whitelist ═══════════════════════
   The satellite's own ground stations, each bound to the carrier offset its
   transmitter uses. HnyProto.h explains why a callsign alone is not an
   identity. The table lives in flash so it survives a reset, and it is small
   on purpose: a member satellite talks to a handful of stations.

   Enrolment is a deliberate operator action ('A' after a known-good frame).
   A flight build would fill the table before launch and update it only
   through an authenticated uplink.                                          */
static void fp_save() {
  File f = LittleFS.open(FP_STORE, "w");
  if (!f) { Serial.println("{\"err\":\"fpallow open\"}"); return; }
  for (size_t i = 0; i < nFpAllow; i++)
    f.printf("%s,%.2f,%.2f,%u,%lu\n", fpAllow[i].call, fpAllow[i].bias_khz,
             fpAllow[i].tol_khz, fpAllow[i].conf,
             (unsigned long)fpAllow[i].hits);
  f.close();
}

static void fp_load() {
  nFpAllow = 0;
  File f = LittleFS.open(FP_STORE, "r");
  if (f) {
    while (f.available() && nFpAllow < FP_MAX) {
      String line = f.readStringUntil('\n');
      if (line.length() < 5) continue;
      FpAllow e = {};
      float bias = 0, tol = 0; unsigned conf = 0; unsigned long hits = 0;
      char call[10] = {0};
      if (sscanf(line.c_str(), "%9[^,],%f,%f,%u,%lu",
                 call, &bias, &tol, &conf, &hits) >= 4) {
        strncpy(e.call, call, sizeof(e.call) - 1);
        e.bias_khz = bias; e.tol_khz = tol;
        e.conf = (uint8_t)conf; e.hits = (uint32_t)hits;
        fpAllow[nFpAllow++] = e;
      }
    }
    f.close();
  }
  if (nFpAllow == 0) {
    // First boot: the operator's own station, enrolled at the offset it uses
    // on this bench (GS104 transmits on 0.0 kHz, see BENCH_GS in HnyProto.h).
    FpAllow e = {};
    strncpy(e.call, "GS104", sizeof(e.call) - 1);
    e.bias_khz = 0.0f; e.tol_khz = FP_ENROL_TOL_KHZ; e.conf = 90; e.hits = 0;
    fpAllow[nFpAllow++] = e;
    fp_save();
  }
}

static void fp_print() {
  Serial.printf("[wl] %u/%u entries\n", (unsigned)nFpAllow, FP_MAX);
  for (size_t i = 0; i < nFpAllow; i++) {
    char sig[18];
    hny_signature(fpAllow[i].call, fpAllow[i].bias_khz, sig, sizeof(sig));
    Serial.printf("[wl]  %-10s %-12s bias=%+.2f kHz tol=%.2f conf=%u hits=%lu\n",
                  fpAllow[i].call, sig, fpAllow[i].bias_khz, fpAllow[i].tol_khz,
                  fpAllow[i].conf, (unsigned long)fpAllow[i].hits);
  }
}

/* Enrol, or re-enrol, the transmitter of the last frame. Re-enrolling an
   existing callsign moves its entry instead of adding a second one: two
   entries for one callsign would widen the window an impersonator has to hit. */
static void fp_enroll(const char *src, float dev_khz) {
  for (size_t i = 0; i < nFpAllow; i++) {
    if (strcmp(fpAllow[i].call, src)) continue;
    fpAllow[i].bias_khz = dev_khz;
    fpAllow[i].tol_khz = FP_ENROL_TOL_KHZ;
    fpAllow[i].conf = 90;
    fpAllow[i].hits = 0;
    fp_save();
    Serial.printf("[wl] re-enrolled %s at %+.2f kHz\n", src, dev_khz);
    return;
  }
  if (nFpAllow >= FP_MAX) { Serial.println("[wl] table full"); return; }
  FpAllow e = {};
  strncpy(e.call, src, sizeof(e.call) - 1);
  e.bias_khz = dev_khz; e.tol_khz = FP_ENROL_TOL_KHZ; e.conf = 90; e.hits = 0;
  fpAllow[nFpAllow++] = e;
  fp_save();
  Serial.printf("[wl] enrolled %s at %+.2f kHz (tol %.2f)\n",
                src, dev_khz, FP_ENROL_TOL_KHZ);
}

/* ═══════════════════════════ common-mode Doppler estimate ════════════════
   The whitelist must be checked on the residual (the carrier offset with the
   pass Doppler removed), and the bench has no orbit model. It does not need
   one: every cooperating station pre-compensates the same pass profile, so
   subtracting each station's known bias from its measured offset leaves the
   common motion. The median of the last DOP_WIN such samples estimates it,
   and a fixed-frequency attacker is an outlier the median ignores.

   A flight board would take this value from its orbit propagator. With fewer
   than DOP_MIN_N samples the estimate is zero (fail-open): the residual is
   then the raw offset and the whitelist has less to say.                     */
static float dop_estimate_khz() { return (dopN >= DOP_MIN_N) ? dopEstKhz : 0.0f; }

static void dop_update(const char *src, float dev_khz) {
  float bias;
  if (!bench_bias_khz(src, &bias)) return;      // unknown callsign: no information
  dopWin[dopI] = dev_khz - bias;
  dopI = (dopI + 1) % DOP_WIN;
  if (dopN < DOP_WIN) dopN++;
  float tmp[DOP_WIN];
  memcpy(tmp, dopWin, sizeof(float) * dopN);
  for (uint8_t i = 1; i < dopN; i++) {          // insertion sort, n <= 8
    float v = tmp[i]; int8_t j = i - 1;
    while (j >= 0 && tmp[j] > v) { tmp[j + 1] = tmp[j]; j--; }
    tmp[j + 1] = v;
  }
  dopEstKhz = (dopN & 1) ? tmp[dopN / 2]
                         : 0.5f * (tmp[dopN / 2 - 1] + tmp[dopN / 2]);
}

/* ═══════════════════════════ records and LEDs ═════════════════════════════ */

/* Record identifier: SHA-256 over the frame's own fields, first 10 bytes. */
static void fingerprint(const Record &r, char *out21) {
  char feat[128];
  snprintf(feat, sizeof(feat), "%s|%.5f|%.1f|%s", r.src, r.freq_dev_khz, r.dop_hz, r.cmd);
  uint8_t d[32];
  mbedtls_sha256_context c; mbedtls_sha256_init(&c);
  mbedtls_sha256_starts(&c, 0);
  mbedtls_sha256_update(&c, (const uint8_t *)feat, strlen(feat));
  mbedtls_sha256_finish(&c, d); mbedtls_sha256_free(&c);
  for (int k = 0; k < 10; k++) snprintf(out21 + 2 * k, 3, "%02X", d[k]);
}

static void store_record(const Record &r) {
  File f = LittleFS.open(STORE, "a");
  if (!f) { Serial.println("{\"err\":\"store open\"}"); return; }
  f.write((const uint8_t *)&r, sizeof(Record));
  f.close();
  nStored++;
}

/* The verdict LEDs hold the last verdict until the next frame replaces it,
   so that frames arriving close together can still be read off the board. */
static void leds_off() {
  digitalWrite(PIN_LED, LOW);
  digitalWrite(PIN_LED_Y, LOW);
  digitalWrite(PIN_LED_G, LOW);
}

static void led_show(int pin) {
  leds_off();
  digitalWrite(pin, HIGH);
}
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
void loop() {
  service_tx_blanking();
  if (rxFlag) { rxFlag = false; if (!rxBlanked) handle_uplink(); }
  rx_watchdog();
  radio_health();

  if (Serial.available()) {
    char c = Serial.read();
    if (c == 'D' || c == 'd') downlink();
    else if (c == 'S' || c == 's') status();
    else if (c == 'Q' || c == 'q') band_scan();
    else if (c == 'P' || c == 'p') power_profile();
    else if (c == 'E' || c == 'e') { LittleFS.remove(STORE); nStored = 0; Serial.println("[hny] store erased"); }
    else if (c == 'F' || c == 'f') { fp_save(); fp_print(); }
    else if (c == 'A' || c == 'a') {
      if (!haveLastPkt) Serial.println("[wl] no packet heard yet");
      else fp_enroll(lastSrc, lastResidKhz);
    }
    else if (c == 'X' || c == 'x') {
      nFpAllow = 0; fp_save();
      Serial.println("[wl] whitelist cleared — fail-open until re-enrolled");
    }
    else if (c == 'R' || c == 'r') { memset(&perf, 0, sizeof(perf)); Serial.println("[hny] perf counters reset"); }
    else if (c == 'M' || c == 'm') {
      mode = (mode == MODE_MEMBER) ? MODE_HONEYPOT : MODE_MEMBER;
      leds_off();
      Serial.printf("[hny] mode: %s\n", mode_name());
    }
  }
  if (digitalRead(PIN_BOOT) == LOW) { delay(50); if (digitalRead(PIN_BOOT) == LOW) { downlink(); while (digitalRead(PIN_BOOT) == LOW) delay(10); } }
}

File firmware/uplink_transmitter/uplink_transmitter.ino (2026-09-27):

/* ═══════════════════════════════════════════════════════════════════════════
   Uplink transmitter — Raspberry Pi Pico + SX1278 (Dorji DRF1278F)

   Generates the uplink scenario the honeypot node is tested against. It plays
   five legitimate ground stations, each with its own callsign, carrier offset
   and command pattern, and after each of them sends one frame from a rotating
   list of attacks:

     UNK968 REBOOT              off frequency (+28 kHz), unknown source,
                                suspicious command
     GS104  ERASE_FLASH         the operator's own callsign from another radio
     UNK971 0x7F_UNKNOWN_OPCODE probing: unknown opcode, 0.9 s after the
                                previous frame, +24 kHz
     GS107  EPS_STATUS          Doppler spoof: correct callsign, bias and
                                command, but a fixed carrier (no Doppler tracking)
     GS102  HK_DUMP             malformed frame: everything correct except the
                                AX.25 FCS

   Frames are AX.25 UI frames SRC=<callsign> -> DST=HNY1 whose info field is
   "<seq>|<command>", sent as 2-FSK on 433.5 MHz (ISM band) at 2 dBm.

   The bench does not move, so the transmitter applies a simulated pass
   Doppler to its own carrier. Legitimate stations pre-compensate it, as a real
   ground station does; the attackers transmit on a fixed frequency.

   Hardware
     Raspberry Pi Pico, Dorji DRF1278F (SX1278)

   Wiring
     DRF1278F  SCK  -> GP18    MOSI -> GP19    MISO -> GP20    NSS -> GP17
               RESET -> GP22   DIO0 -> GP21    VCC  -> 3V3(OUT)  GND -> GND

   Build
     Board "Raspberry Pi Pico" (arduino-pico core), libraries RadioLib 7.7.1
     and HnyProto.

   Output (USB serial, 115200 baud): one "[up] ..." line per frame, read by
   analysis/benchlog.py and tools/uplink_monitor.
   ═══════════════════════════════════════════════════════════════════════════ */
#include <RadioLib.h>
#include <HnyProto.h>

/* ── pins and radio ───────────────────────────────────────────────────── */
#define PIN_SCK 18
#define PIN_MOSI 19
#define PIN_MISO 20   // any SPI0 RX-capable pin (GP0, GP4, GP16, GP20)
#define PIN_NSS 17
#define PIN_RST 22
#define PIN_DIO0 21
SX1278 radio = new Module(PIN_NSS, PIN_DIO0, PIN_RST, RADIOLIB_NC);

static const float CENTER_MHZ = 433.5f;

/* ── simulated pass Doppler ───────────────────────────────────────────────
   Straight-line flyby: r(t) = sqrt(d^2 + (v t)^2), range rate
   rdot = v^2 t / r, Doppler = -(rdot / c) f0, with t = 0 at closest approach.

   The amplitude is scaled for the bench, like the station offsets in
   HnyProto.h: a full-scale profile at 433.5 MHz peaks near 10.7 kHz, which on
   top of a +-8 kHz station offset would come close to the 20 kHz
   frequency-deviation threshold. A 6 kHz peak keeps the shape and the timing
   and leaves margin.                                                        */
static const float PASS_S      = 600.0f;      // 10-minute pass
static const float DOP_PEAK_HZ = 6000.0f;     // bench-scaled peak
static const float SAT_V_MS    = 7600.0f;     // LEO ground-relative speed
static const float SLANT_M     = 600000.0f;   // slant range at closest approach

static uint32_t passT0Ms = 0;

/* +DOP_PEAK_HZ at pass start (approaching), 0 at closest approach,
   -DOP_PEAK_HZ at pass end (receding).                                    */
static float doppler_hz(float t_s) {
  float t   = t_s - PASS_S * 0.5f;
  float vt  = SAT_V_MS * t;
  float rd  = (SAT_V_MS * SAT_V_MS * t) / sqrtf(SLANT_M * SLANT_M + vt * vt);
  float te  = PASS_S * 0.5f, vte = SAT_V_MS * te;
  float rdm = (SAT_V_MS * SAT_V_MS * te) / sqrtf(SLANT_M * SLANT_M + vte * vte);
  return -DOP_PEAK_HZ * (rd / rdm);
}

/* seconds into the current pass; passes repeat back to back */
static float pass_t_s() {
  return fmodf((float)(millis() - passT0Ms) / 1000.0f, PASS_S);
}

/* ── scenario ─────────────────────────────────────────────────────────── */
// command and interval of each legitimate station (callsigns and offsets are
// BENCH_GS in HnyProto.h)
struct GsBehaviour { const char *cmd; uint32_t gap_ms; };
static const GsBehaviour GS_TRAFFIC[N_BENCH_GS] = {
  {"TLM_REQ",      7000},   // GS100
  {"HK_DUMP",      9000},   // GS102
  {"PING",         5000},   // GS104
  {"EPS_STATUS",   8000},   // GS107
  {"PASS_SCHEDULE",11000},  // GS109
};

// Attack frames, sent one after each legitimate station. `dop` says whether
// the frame pre-compensates Doppler (an attacker without an orbit model does
// not), `corrupt` breaks the AX.25 FCS.
struct Attack { const char *src; const char *cmd; float freq_off_khz;
                uint32_t gap_ms; const char *what; bool dop; bool corrupt; };
static const Attack ATTACKS[] = {
  {"UNK968", "REBOOT",        28.0f, 4000, "freq+unknown+cmd", false, false},
  {"GS104",  "ERASE_FLASH",    0.0f, 4000, "callsign spoof",   false, false},
  {"UNK971", "0x7F_UNKNOWN_OPCODE", 24.0f, 900, "probing burst", false, false},
  // Doppler mismatch in isolation: a known callsign with its correct offset
  // and a benign command, so only the Doppler residual gives it away.
  {"GS107",  "EPS_STATUS",     4.0f, 5000, "doppler spoof",    false, false},
  // Malformed frame in isolation: everything correct except the AX.25 FCS,
  // so only the malformed-packet indicator fires.
  {"GS102",  "HK_DUMP",       -4.0f, 4000, "malformed FCS",    true,  true},
};
static const size_t N_ATT = sizeof(ATTACKS) / sizeof(ATTACKS[0]);

static uint32_t seq = 0;
static size_t attIdx = 0;
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

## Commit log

2026-09-25 CTI CubeSat bench: honeypot node, test transmitter, CTI ground station
2026-09-27 Restructure the repository for public release
    Honeypot node, uplink transmitter and link test firmware with tidied
    sources; Raspberry Pi receiver, CTI server and web portal; synthetic
    simulation pipeline; analysis scripts with the 2026-09-25 campaign data;
    Fritzing sketches; full documentation in English; MIT licence.
    [ground_station.fzz, honeypot_node.fzz, uplink_transmitter.fzz]
2026-09-27 Show the wiring schematics instead of bench photos
2026-09-27 Add the bench photos back next to the schematics
2026-09-27 Update the transmitter schematic and show schematics only
2026-09-27 Fix the wiring schematics and the LED resistor values
    The transmitter schematic now wires the radio's supply and ground. The
    honeypot schematic has the INA219 the right way round, connected
    decoupling capacitors and the LED series resistors. The ground-station
    schematic draws the Ra-01 itself instead of the DRF1278F symbol. The LED
    resistors in the docs now match the bench (220 Ω, amber 100 Ω).
    [ground_station.fzz, honeypot_node.fzz, uplink_transmitter.fzz]
2026-09-27 Name the sketch inside each Fritzing file after its node
    [ground_station.fzz, honeypot_node.fzz, uplink_transmitter.fzz]
